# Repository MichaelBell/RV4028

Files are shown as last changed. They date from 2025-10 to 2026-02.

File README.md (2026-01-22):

# RV4028 - A hackable Risc-V computer

RV4028 is intended to be a modular Risc-V computer, similar to the excellent [RC2014 Z80](https://rc2014.co.uk/) homebrew computer.

The idea is to create a minimal Risc-V system that is easy to understand and extend.

The inspiration for this came from [@theJPster](https://github.com/thejpster)'s [post](https://bsky.app/profile/thejpster.org.uk/post/3m3ngtx5sfc2i).

All hardware and software are open source and permissively licensed.

## Architecture

The system bus has a 32-bit address and 16-bit data, which fits reasonably well with an RV32 system and readily available (P)SRAM chips, and runs at 3.3V.

Modules are attached by an 80-pin dual row header, similar to RC2014 modules but with 2 rows of pins instead of 1.  2mm pitch headers are used instead of 2.54mm, this makes boards slightly smaller (and cheaper), and also avoids the possibility of boards being plugged into RC2014 by mistake.

However, the pinout is chosen such that RC2014 modules might be compatible, if 3v3 capable components are used and a backplane with additional 2.54mm pitch sockets were created.  The pinout is also chosen such that modules not requiring access to the full bus can use just a single row.

Bus connector

## Software

The intention is to be able to run standard RV32I programs with a C SDK.  A Micropython port and Rust support are likely.

It is currently not a goal to support either real time operating systems (although this may be possible in future), or Linux (which would likely not be possible without moving to a larger FPGA).

# Initial modules

## CPU

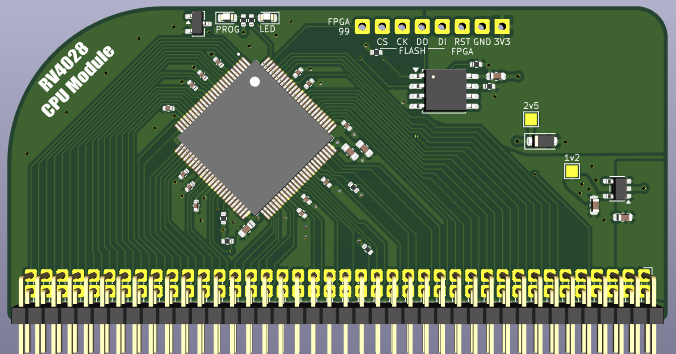
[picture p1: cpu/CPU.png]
CPU Module render


Keeping things minimal and simple, we use a Bruno Levy's [FemtoRV](https://github.com/BrunoLevy/learn-fpga/tree/master/FemtoRV) Quark (RV32I) core with some small modifications, and a wrapper to handle breaking each 32-bit data access into 16-bit accesses.  This is the most minimal Risc-V instruction set and can fit in a small FPGA, so we use an ICE40 [HX1K](https://www.latticesemi.com/ice40), which is available in a 100-pin QFP.

A small flash is required for the FPGA configuration, a header will be provided that will allow the FPGA to be held in reset and the flash programmed.  Although it is significantly larger than required, using a 1MB [W25Q80DV](https://www.lcsc.com/datasheet/C14086.pdf) seems cost effective. 

[Schematic](cpu/cpu.pdf)

## RAM

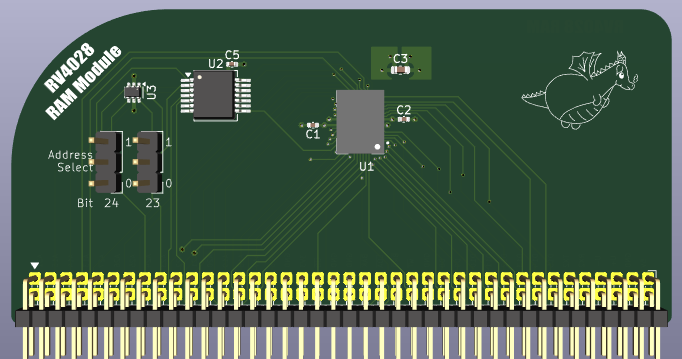
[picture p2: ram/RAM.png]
RAM Module render


The two candidates here are PSRAM, such as the [IS66WVE](https://www.lcsc.com/datasheet/C1350157.pdf), or SRAM such as the [CY7C1041G30](https://www.lcsc.com/datasheet/C2944680.pdf).

The PSRAM is larger but slower, and the larger capacities only seem available in BGA packages.  The linked SRAM is available in TSOP, which may allow for easier assembly.

The current RAM module uses the PSRAM.

[Schematic](ram/ram.pdf)

## ROM

Something like [SST39VF3202C](https://www.lcsc.com/datasheet/C637403.pdf) looks suitable, and available at the same access speed as the PSRAM (70ns).

ROM might not be required - we can embed a small amount of ROM (6kB) in the CPU gateware which could be enough for a simple SD card driver, allowing a program to be loaded from SD card to RAM without any ROM.

## IO

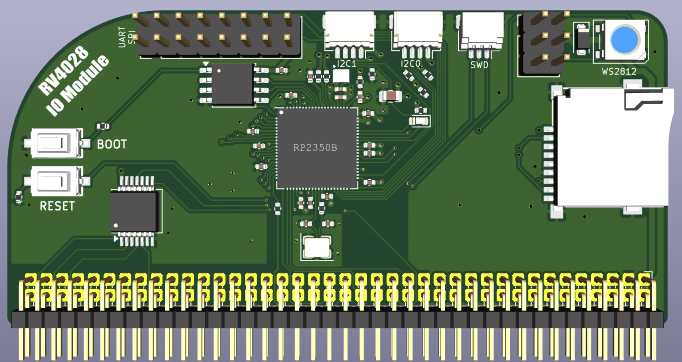
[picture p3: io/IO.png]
IO Module render


An [RP2350B](https://datasheets.raspberrypi.com/rp2350/rp2350-datasheet.pdf) is used for IO.  The board should include:
- Two UARTs
- Two I2C broken out to Qw/ST compatible ports
- A micro SD card socket
- An SPI with a couple of chip selects (this should be made easy to connect to the CPU for updating the gateware)
- Some GPIO

8 bits of address should easily be sufficient, and 8 bits of data should also be fine, which allows this to be single row.

I'm tempted to put USB on a couple of the spare backplane pins, so a single USB connection can power the system and be used to communicate with/program the RP2350.

If we also wired clock and reset from the RP2350 then it could provide a clock, meaning a separate clock module would not be required.

[Schematic](io/io.pdf) | [More details](io/README.md)

## Clock

As above, a clock module likely won't be required, but it is a nice educational addition, and would allow the machine to be used without the RP2350 based IO module.

A 14.7456MHz crystal would seem appropriate - double the clock rate of the RC2014.  Assuming IS66WVE PSRAM is used, the maximum reliable clock rate of the system should be around 17-18MHz (TBC).

An [SN74LVC1GX04](https://www.lcsc.com/datasheet/C2653063.pdf) could be used to drive the crystal.

## Backplane

USB-C socket, with data wired to spare pins for RP2350 on IO board.

AP2112K for 3.3V supply.  3v3 enable is delayed by a few milliseconds to help with power sequencing on the CPU board (the core power to the FPGA should be applied before IO voltage).

Decoupling caps, LED, reset button.  Use surface mount headers for the 2x40 pin connectors, allows all the signals to run above a nice unbroken ground plane, rather than having loads of through holes breaking up the ground planes.

# Bus timing

Addresses are always 16-bit aligned and a byte mask is used for single byte stores.

All writes complete in a two cycles.  Reads normally complete in two cycles, but wait may be asserted to extend the read cycle.

MREQ is intended to be wired to the (P)SRAM CE, so must be pulsed regularly even if reads are continuous in order to avoid exceeding max CE assertion time on PSRAM.  This is acheived by pulsing it high in the first half clock of each read cycle.  MREQ remains low at the start of a write cycle in order to support a faster clock speed when used with a IS66WVE.

IORQ is not required as the address space is sufficiently large.  It is simply set to ~A31.

LO_ADDR indicates if the address is in the bottom 16MB of the address space, to reduce the amount of address checking logic required on low addressed modules.

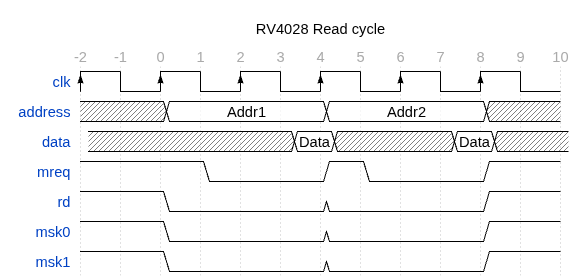
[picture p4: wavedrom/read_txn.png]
Read timing diagram


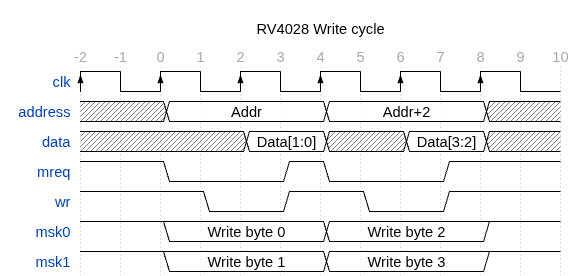
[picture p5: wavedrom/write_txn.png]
Write timing diagram


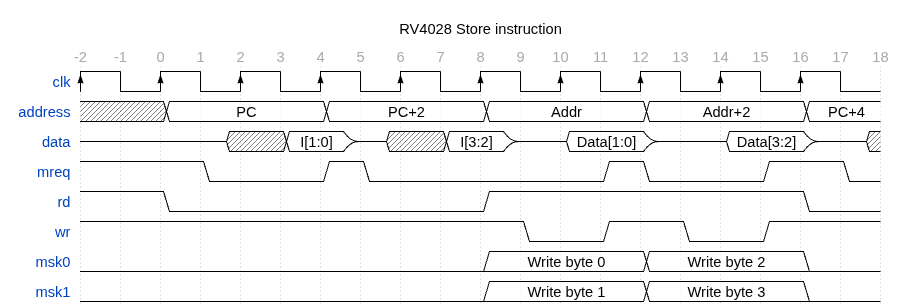
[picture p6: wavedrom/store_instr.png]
Full store instruction


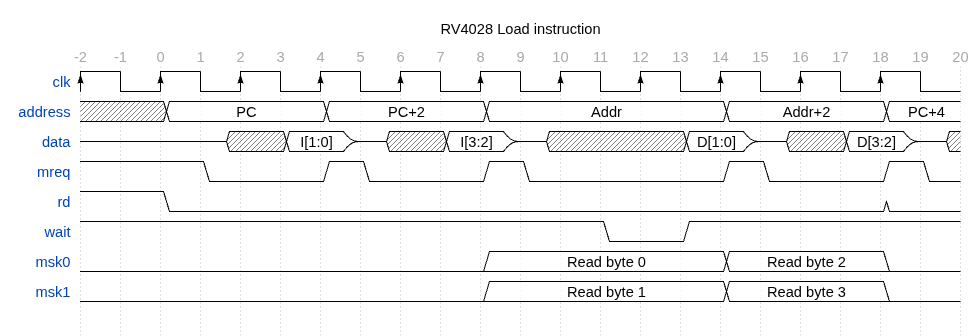
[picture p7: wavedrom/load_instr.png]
Full load instruction


## Expected RAM implementation

RAM access is controlled by CE, OE, WE and byte selects.

* Address high bits are compared for the chip, CE is never asserted if the address doesn't match
* CE is MREQ
* WE is WR
* OE is RD
* Byte selects are MSK.

Writes are latched by deasserting WE and CE.  So a full store instruction that read the instruction and wrote data back to the same RAM chip would look like:

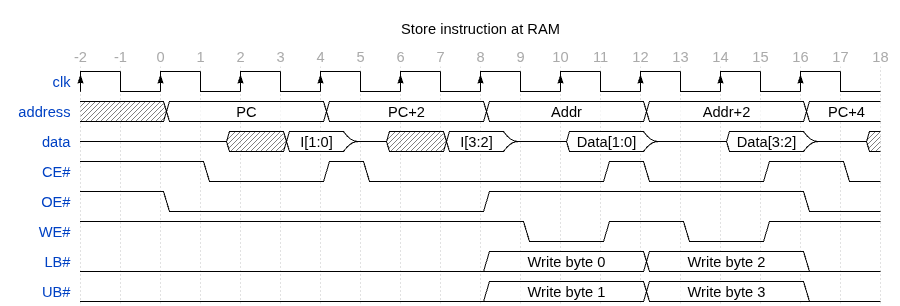
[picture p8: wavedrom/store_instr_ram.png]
Full store instruction to RAM


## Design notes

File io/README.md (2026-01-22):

# RP2350 IO module for RV4028

## Features

Basic idea is to expose the RP2350's hardware blocks as memory mapped peripherals.

Peripherals:
- 2 UARTs (one to backplane, one on headers)
- 2 I2C (QwST connectors)
- 1 SPI with 3 or 4 chip selects (can be used for programming the FPGA)
- SD card
- Maybe a WS2812 interface (exposing 5V power)
- Further pins as general purpose IO.  Maybe could expose a PIO block?

Clock and reset are connected, and can optionally be driven, depending on the loaded firmware.

WAIT and INT should be connected.

Other wiring:
- USB to the USB pins on the backplane
- SWD to a header

## Interface

Byte at a time data - this is very suitable for UART, I2C, SPI.

Address - A1-A7 connected, plus ~A31 and A30-A28 ORed together, with the module selected when the result is low.  The modules canonical address space is therefore even addresses within 0x8FFF_FF00 - 0x8FFF_FFFF.  Accessing it at other addresses should be avoided to prevent conflicting responses from different modules (maybe we put some protection in the gateware to prevent access to invalid addresses?)

IOSEL = ~A31 OR A30 OR A29 OR A28, RDREQ = REQ OR RD and WR are needed in addition to the 7 low address pins and 8 data pins.

## Implementation

PIO programs are used to detect read and write accesses.

### Write

Watches for WR going low and then checks IOSEL, if it is high the transaction is not for this module.

If low, the address and data pins are DMA'd from the PIO into a ring buffer and an IRQ asserted to wake a CPU task to read the ring buffer.

The CPU reads while the ring buffer is not empty, and forwards the data to the peripheral based on the memory map.

PIO waits for WR to go high.

### Read

Watches for RDREQ going low and then checks IOSEL, if it is high the transaction is not for this module.

If low, the address is DMA'd to the trigger read address of a waiting DMA channel.  This reads from a table of source addresses into the read trigger address of a second waiting DMA channel, which will DMA one byte from (normally) a peripheral address to the PIO, which will set the data pins.  When RDREQ goes high the data are set back to inputs and the PIO resets.

Latency from RDREQ going low to data being presented should be around 10-15 cycles:
- Wait (2 cycles input latency)
- Jmp
- In pins (auto push)
- DMA trigger
- DMA read from lookup table
- DMA write and trigger
- DMA read from peripheral
- Out pins (auto pull)

This has a little less than 1.5 cycles to complete if WAIT isn't asserted, so is rather tight but should work if the RP2350 clock is > 12x faster than the RV4028 clock.  Could do with prototyping to check the cycle count is acheivable.

### Pin mapping

0-1 UART0 to header
2-3 Ground, so they will read as zero
4-10 A1-A7
11-18 D0-D7
19 CLK
20 RESET
21 INT
22 WAIT
23 IOSEL
24 WR
25 RD
26-27 UART1 to backplane
28-31 SPI1
32-33 I2C0
34-39 SD card (SPI0)
40-41 Additional SPI chip selects
42-43 I2C1
44 WS2812b LED data
45 LED
46-47 GPIO

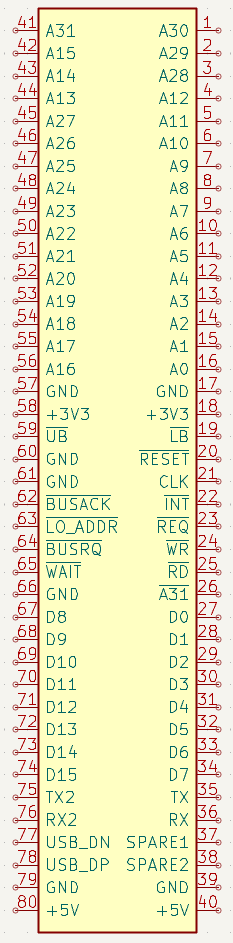
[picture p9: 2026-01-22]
BusConn.png

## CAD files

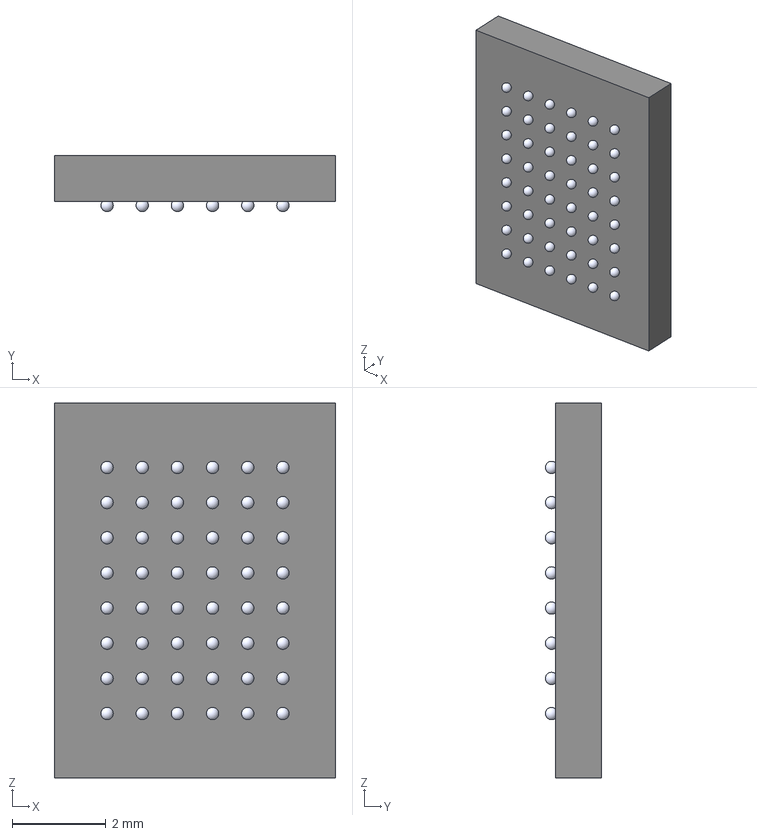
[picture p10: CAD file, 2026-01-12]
kicad/IS66WVE4M16EBLL-70BLI/IS66WVE4M16EBLL-70BLI.step
6.00 x 1.20 x 8.00 mm
Body_Solid1
Body002_Solid1
BALL_0001
BALL_0002
BALL_0003
BALL_0004
BALL_0005
BALL_0006
BALL_0007
BALL_0008
BALL_0009
BALL_0010
BALL_0011
BALL_0012
BALL_0013
BALL_0014
BALL_0015
BALL_0016
BALL_0017
BALL_0018
BALL_0019
BALL_0020
BALL_0021
BALL_0022
BALL_0023
BALL_0024
BALL_0025
BALL_0026
BALL_0027
BALL_0028
BALL_0029
BALL_0030
BALL_0031
BALL_0032
BALL_0033
BALL_0034
BALL_0035
BALL_0036
BALL_0037
BALL_0038
BALL_0039
BALL_0040
BALL_0041
BALL_0042
BALL_0043
BALL_0044
BALL_0045
BALL_0046
BALL_0047
BALL_0048

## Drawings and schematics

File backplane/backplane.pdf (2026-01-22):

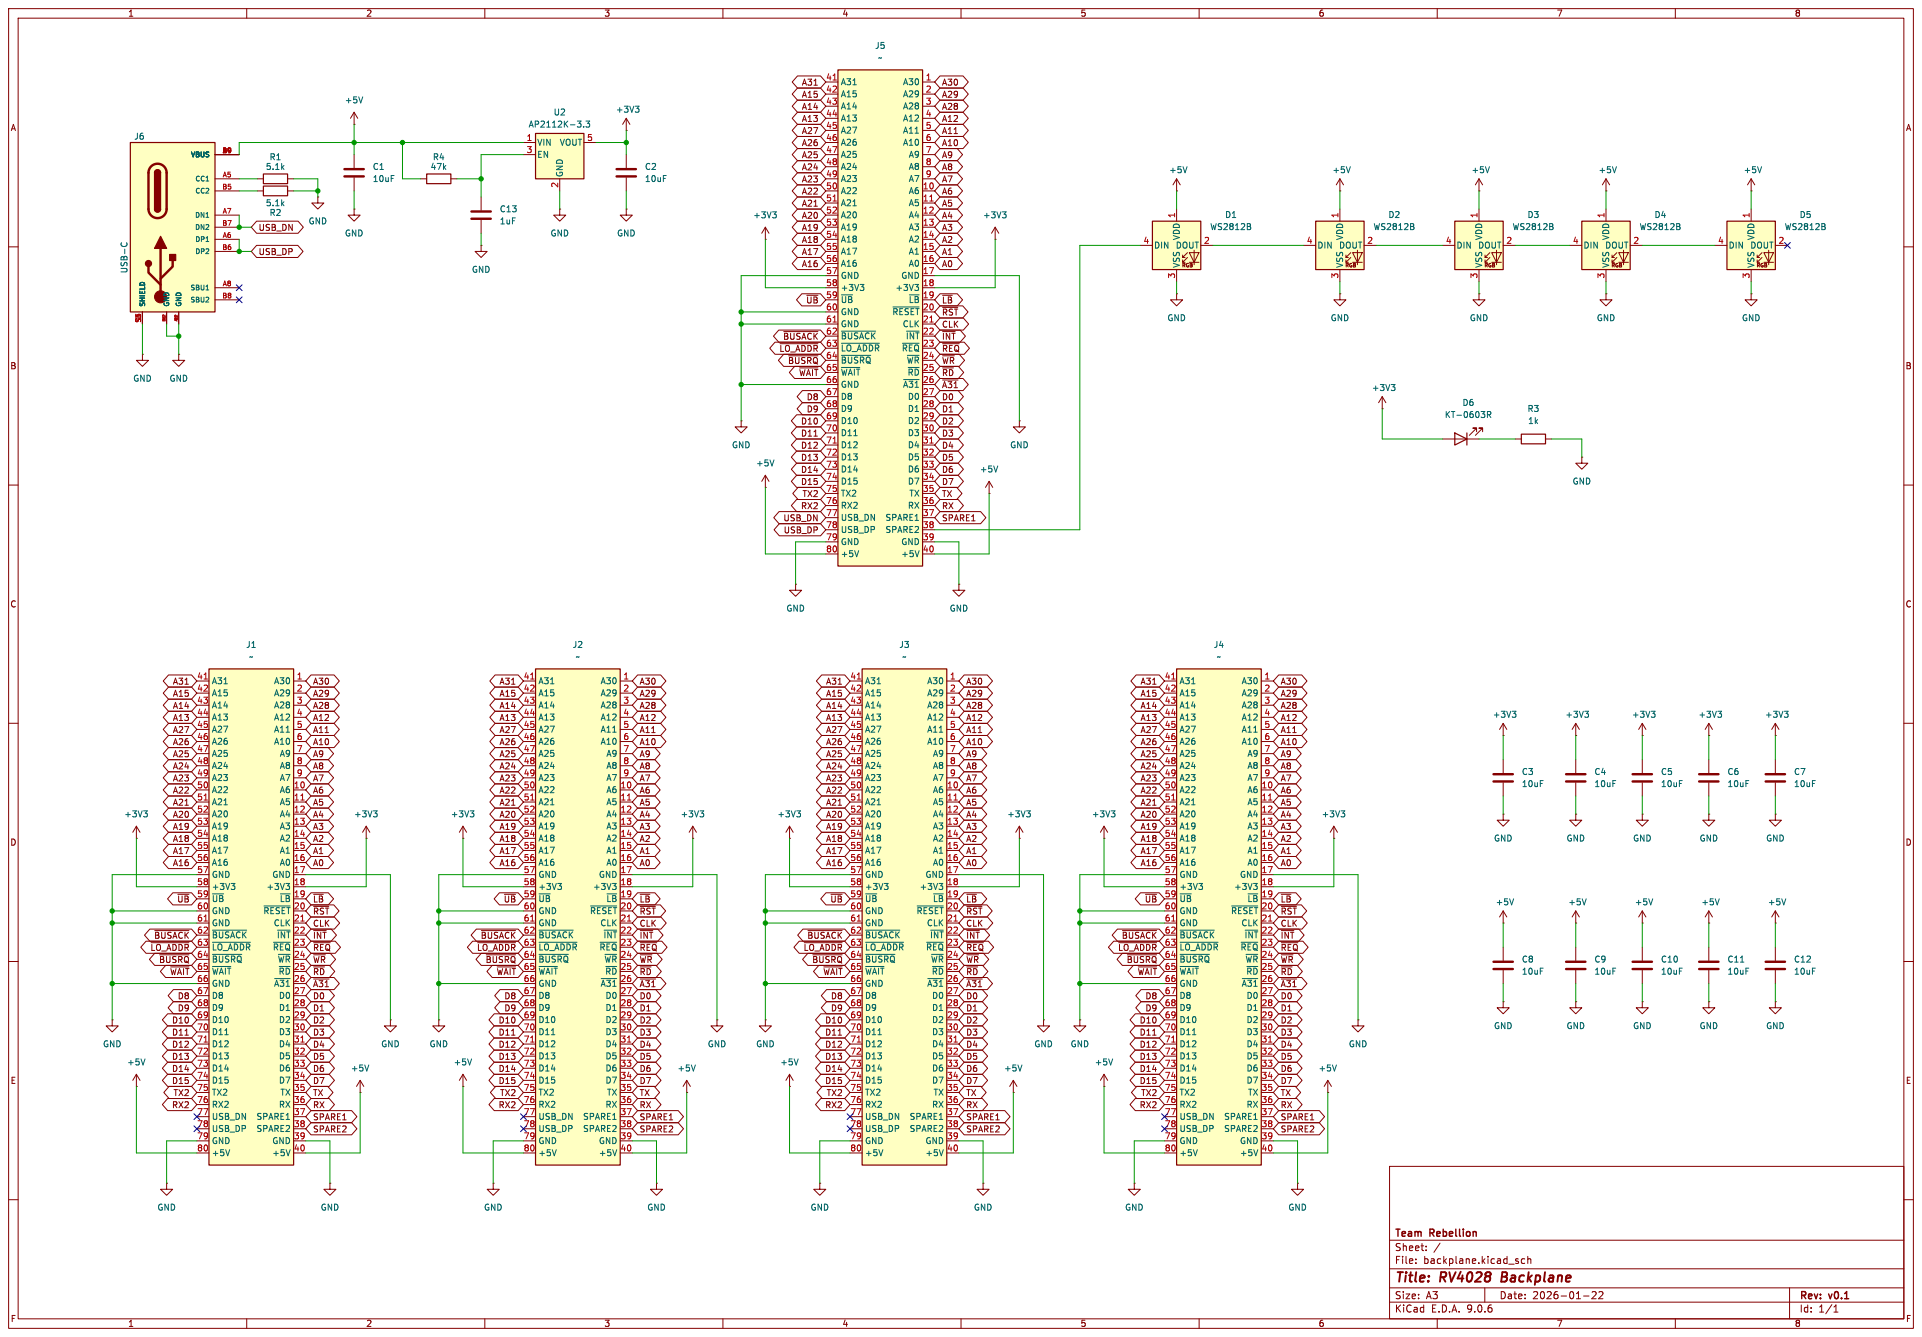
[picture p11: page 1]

1S34 CC1 A5 CC2 B5 DN1 A7 DN2 B7 DP1 A6 DP2 B6 SBU1 A8 SBU2 B8 SHIELD S1 GND A1 B12 GND A12 B1 VBUS B49A J6 USB-C

A30 1 A29 2 A28 3 A12 4 A11 5 A10 6 A9 7 A8 8 A7 9 A6 10 A5 11 A4 12 A3 13 A2 14 A1 15 A0 16 GND 17 +3V3 18 ~{LB}19 ~{RESET} 20 CLK 21 ~{INT} 22 ~{REQ} 23 ~{WR} 24 ~{RD} 25 ~{A31}26 D0 27 D1 28 D2 29 D3 30 D4 31 D5 32 D6 33 D7 34 TX 35 RX 36 SPARE1 37 SPARE2 38 GND 39 +5V 40 ~{BUSACK} 62

USB_DP

A31 41 A15 42 A14 43 A13 44 A27 45 A26 46 A25 47 A24 48 A23 49 A22 50 A21 51 A20 52 A19 53 A18 54 A17 55 A16 56 GND 57 +3V3 58 ~{UB} 59 GND 60 GND 61 ~{LO_ADDR} 63 ~{BUSRQ} 64 ~{WAIT} 65 GND 66 D8 67 D9 68 D10 69 D11 70 D12 71 D13 72 D14 73 D15 74 TX2 75 RX2 76 USB_DN 77 USB_DP 78 GND 79 +5V 80

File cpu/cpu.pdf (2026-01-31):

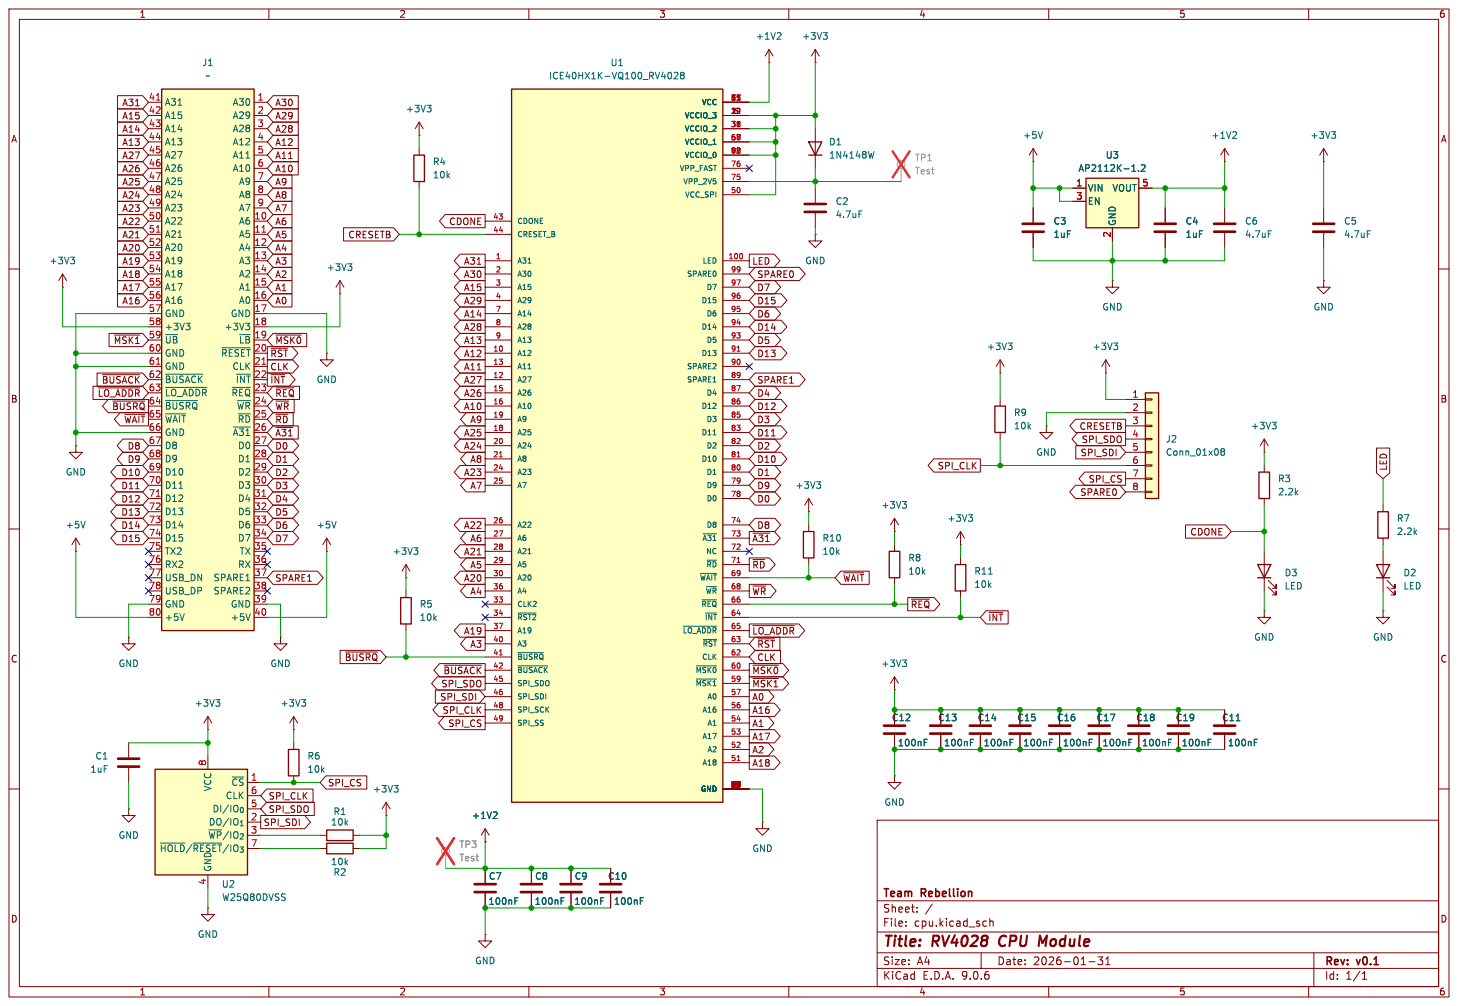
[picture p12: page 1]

~{CS}1 CLK 6 DI/IO_{0}5 DO/IO_{1}2 ~{WP}/IO_{2} 3 ~{HOLD}/~{RESET}/IO_{3} 7 VCC

Id: 1/1 Title: RV4028 CPU Module

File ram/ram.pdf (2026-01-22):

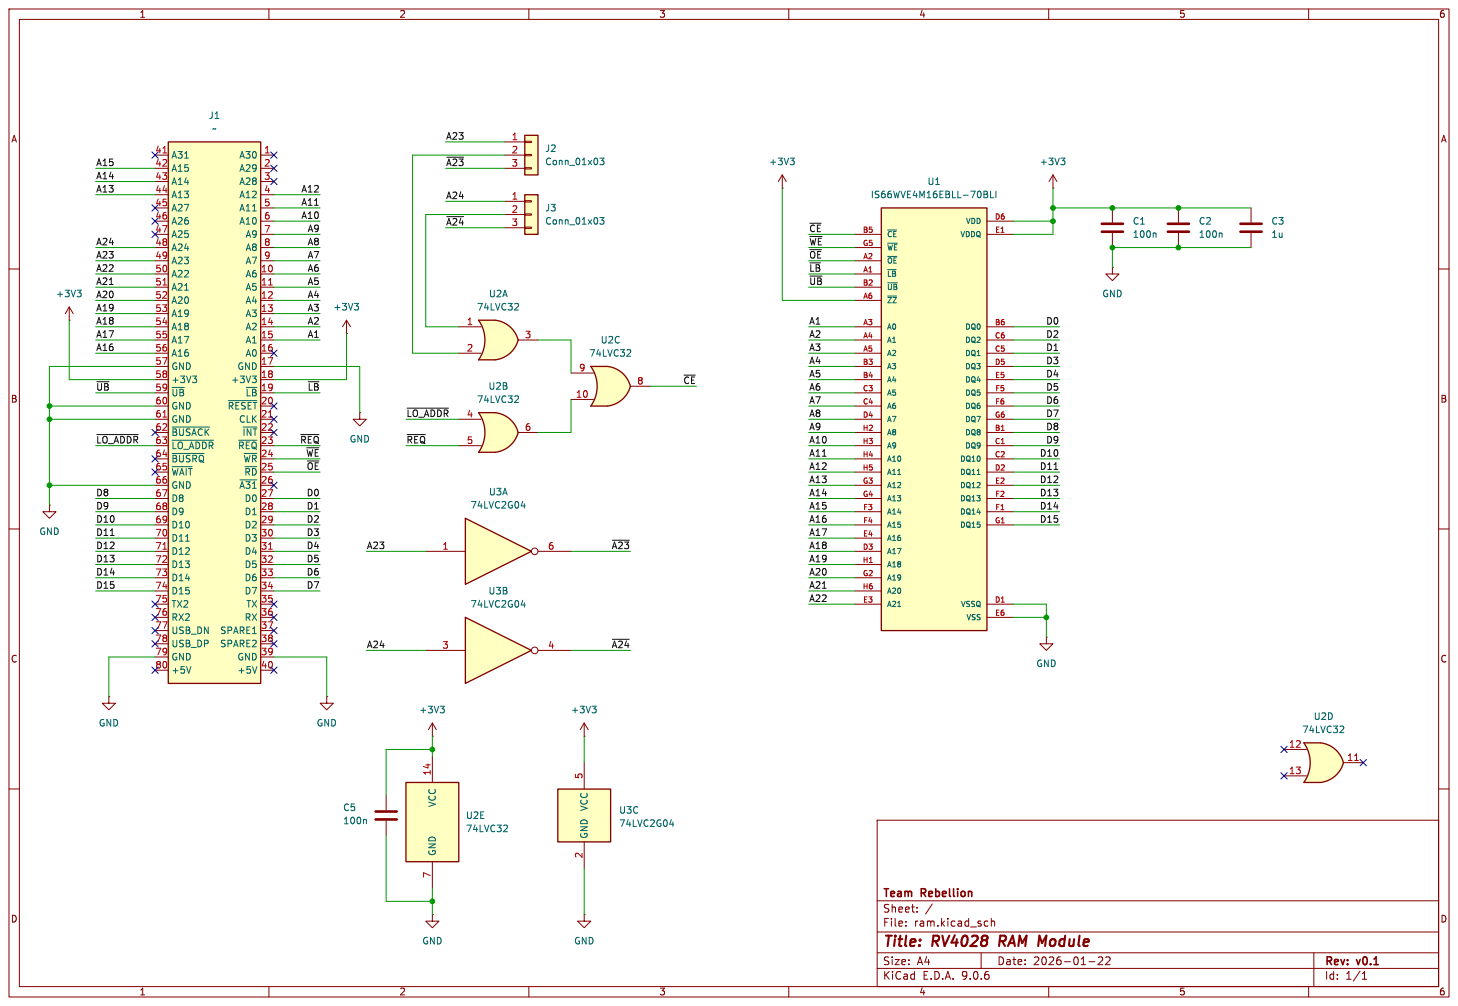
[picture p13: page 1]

Id: 1/1 Title: RV4028 RAM Module

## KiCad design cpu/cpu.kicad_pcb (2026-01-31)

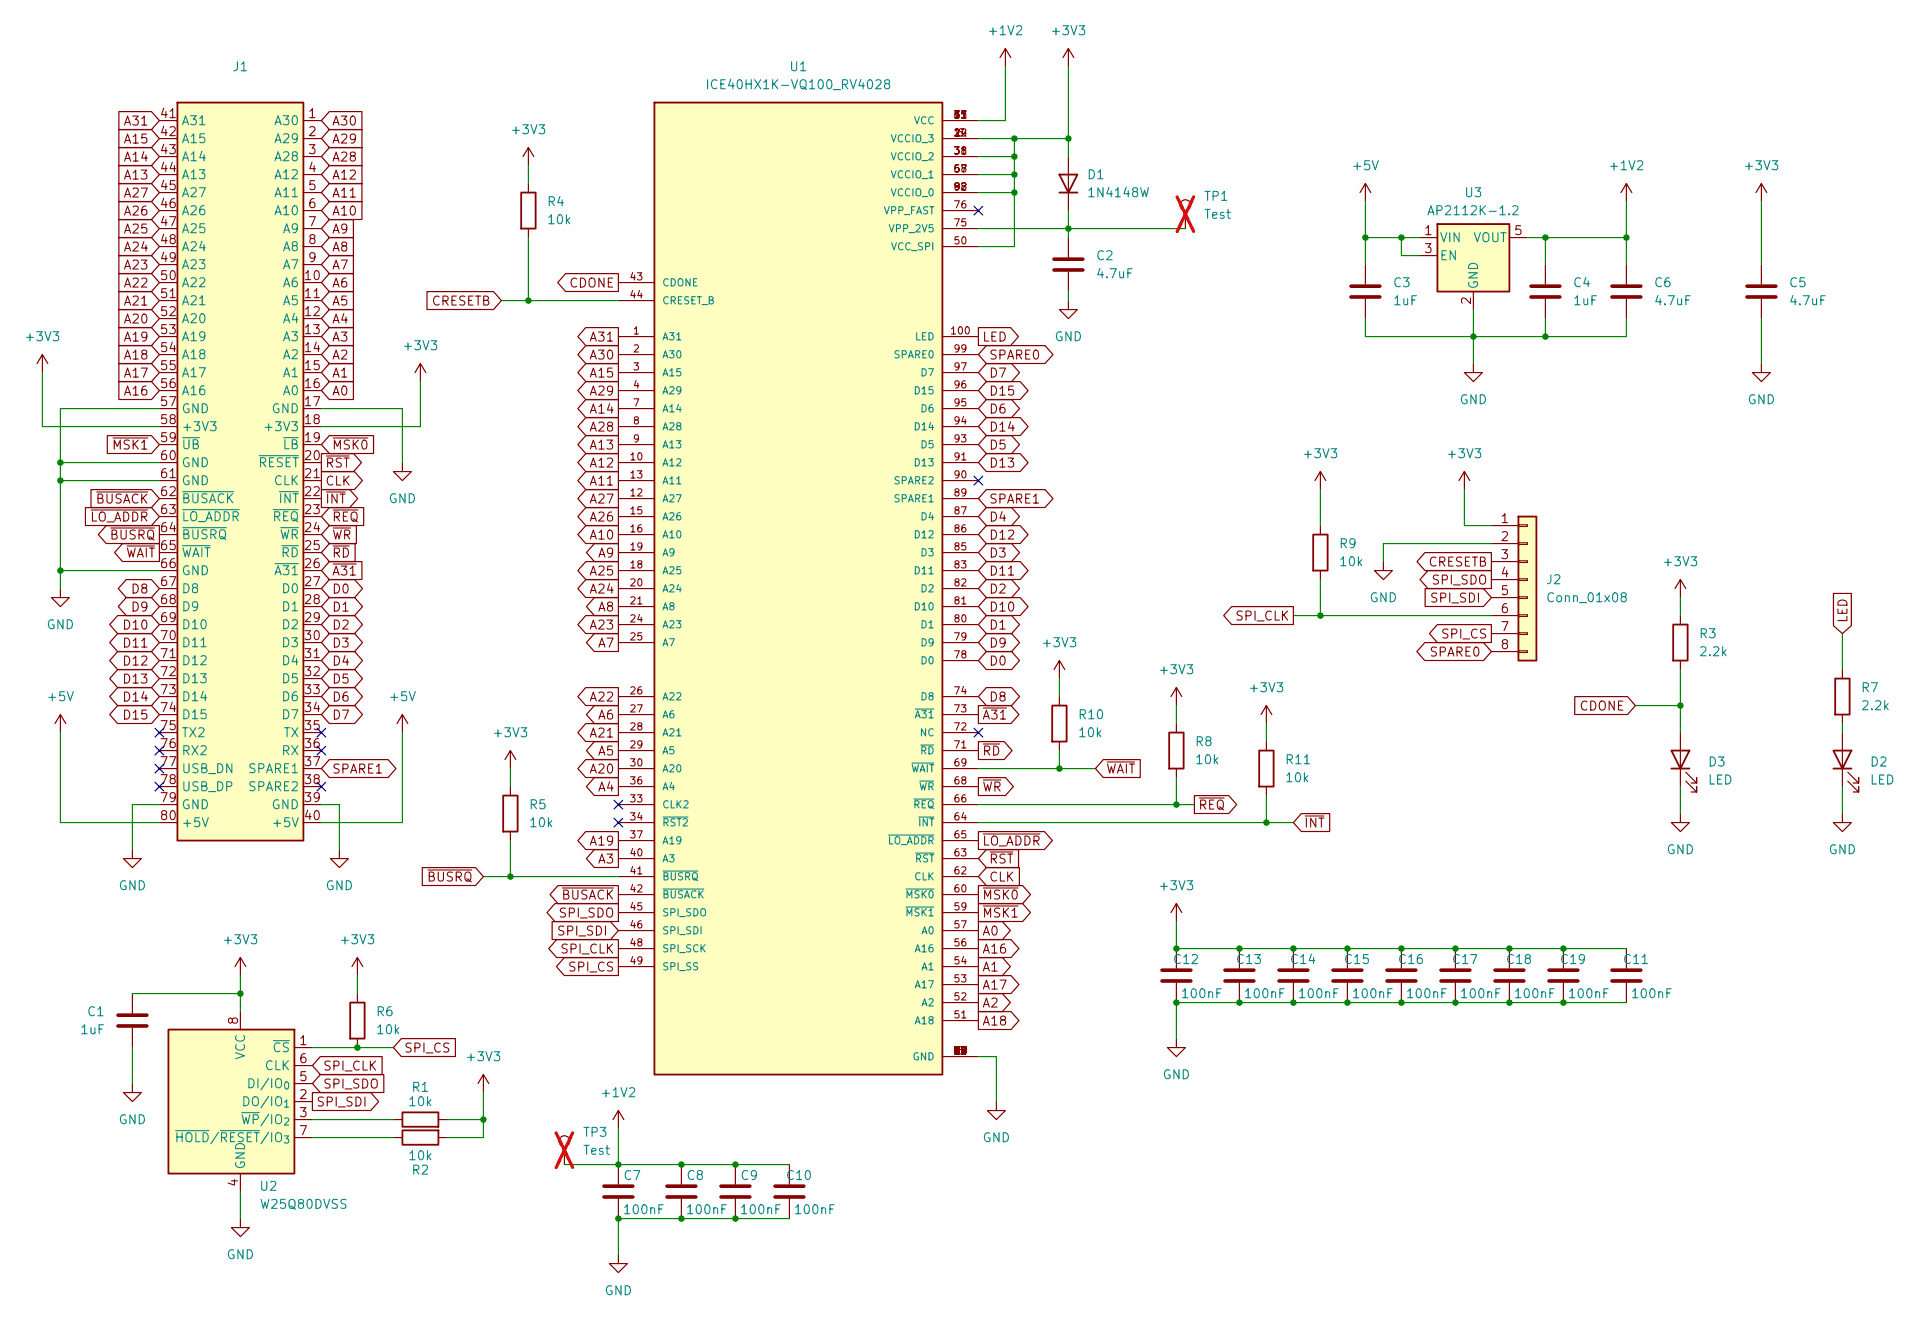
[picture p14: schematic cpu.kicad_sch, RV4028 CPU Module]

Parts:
C1, C3, C4: 1uF; C_0603_1608Metric; JLC C15849
C2, C5, C6: 4.7uF; C_0603_1608Metric; JLC C19666
C7, C8, C9, C10, C11, C12, C13, C14, C15, C16, C17, C18, C19: 100nF; C_0402_1005Metric; JLC C1525
D1: 1N4148W; D_SOD-123F; JLC C81598
D2: LED; LED_0603_1608Metric; JLC C2286
D3: LED; LED_0603_1608Metric; JLC C2290
J1: Module_2mm; JLC C3407
J2: Conn_01x08; PinHeader_1x08_P2.54mm_Vertical; JLC C5383116
R1, R2, R4, R5, R6, R8, R9, R10, R11: 10k; R_0402_1005Metric; JLC C25744
R3, R7: 2.2k; R_0402_1005Metric; JLC C25879
TP1, TP3: Test; TestPoint_Pad_1.5x1.5mm; not fitted
U1: ICE40HX1K-VQ100_RV4028; QFP50P1600X1600X120-100N; PARTREV 3.4; JLC C1519043
U2: W25Q80DVSS; SOIC-8_5.3x5.3mm_P1.27mm; JLC C14086
U3: AP2112K-1.2; SOT-23-5; JLC C460310

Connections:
+1V2: C4.1, C6.1, C7.2, C8.2, C9.2, C10.2, TP3.1, U1.11 (VCC), U1.35 (VCC), U1.61 (VCC), U1.77 (VCC), U3.5 (VOUT)
+3V3: C1.2, C5.1, C11.2, C12.2, C13.2, C14.2, C15.2, C16.2, C17.2, C18.2, C19.2, D1.2 (A), J1.18 (+3V3), J1.58 (+3V3), J2.1, R1.2, R2.2, R3.1, R4.1, R5.1, R6.1, R8.1, R9.1, R10.1, R11.1, U1.6 (VCCIO_3), U1.14 (VCCIO_3), U1.22 (VCCIO_3), U1.31 (VCCIO_2), U1.38 (VCCIO_2), U1.50 (VCC_SPI), U1.58 (VCCIO_1), U1.67 (VCCIO_1), U1.88 (VCCIO_0), U1.92 (VCCIO_0), U2.8 (VCC)
+5V: C3.1, J1.40 (+5V), J1.80 (+5V), U3.1 (VIN), U3.3 (EN)
A0: J1.16 (A0), U1.57 (A0)
A1: J1.15 (A1), U1.54 (A1)
A2: J1.14 (A2), U1.52 (A2)
A3: J1.13 (A3), U1.40 (A3)
A4: J1.12 (A4), U1.36 (A4)
A5: J1.11 (A5), U1.29 (A5)
A6: J1.10 (A6), U1.27 (A6)
A7: J1.9 (A7), U1.25 (A7)
A8: J1.8 (A8), U1.21 (A8)
A9: J1.7 (A9), U1.19 (A9)
A10: J1.6 (A10), U1.16 (A10)
A11: J1.5 (A11), U1.13 (A11)
A12: J1.4 (A12), U1.10 (A12)
A13: J1.44 (A13), U1.9 (A13)
A14: J1.43 (A14), U1.7 (A14)
A15: J1.42 (A15), U1.3 (A15)
A16: J1.56 (A16), U1.56 (A16)
A17: J1.55 (A17), U1.53 (A17)
A18: J1.54 (A18), U1.51 (A18)
A19: J1.53 (A19), U1.37 (A19)
A20: J1.52 (A20), U1.30 (A20)
A21: J1.51 (A21), U1.28 (A21)
A22: J1.50 (A22), U1.26 (A22)
A23: J1.49 (A23), U1.24 (A23)
A24: J1.48 (A24), U1.20 (A24)
A25: J1.47 (A25), U1.18 (A25)
A26: J1.46 (A26), U1.15 (A26)
A27: J1.45 (A27), U1.12 (A27)
A28: J1.3 (A28), U1.8 (A28)
A29: J1.2 (A29), U1.4 (A29)
A30: J1.1 (A30), U1.2 (A30)
A31: J1.41 (A31), U1.1 (A31)
CDONE: D3.2 (A), R3.2, U1.43 (CDONE)
CLK: J1.21 (CLK), U1.62 (CLK)
CRESETB: J2.3, R4.2, U1.44 (CRESET_B)
D0: J1.27 (D0), U1.78 (D0)
D1: J1.28 (D1), U1.80 (D1)
D2: J1.29 (D2), U1.82 (D2)
D3: J1.30 (D3), U1.85 (D3)
D4: J1.31 (D4), U1.87 (D4)
D5: J1.32 (D5), U1.93 (D5)
D6: J1.33 (D6), U1.95 (D6)
D7: J1.34 (D7), U1.97 (D7)
D8: J1.67 (D8), U1.74 (D8)
D9: J1.68 (D9), U1.79 (D9)
D10: J1.69 (D10), U1.81 (D10)
D11: J1.70 (D11), U1.83 (D11)
D12: J1.71 (D12), U1.86 (D12)
D13: J1.72 (D13), U1.91 (D13)
D14: J1.73 (D14), U1.94 (D14)
D15: J1.74 (D15), U1.96 (D15)
GND: C1.1, C2.2, C3.2, C4.2, C5.2, C6.2, C7.1, C8.1, C9.1, C10.1, C11.1, C12.1, C13.1, C14.1, C15.1, C16.1, C17.1, C18.1, C19.1, D2.1 (K), D3.1 (K), J1.17 (GND), J1.39 (GND), J1.57 (GND), J1.60 (GND), J1.61 (GND), J1.66 (GND), J1.79 (GND), J2.2, U1.5 (GND), U1.17 (GND), U1.23 (GND), U1.32 (GND), U1.39 (GND), U1.47 (GND), U1.55 (GND), U1.70 (GND), U1.84 (GND), U1.98 (GND), U2.4 (GND), U3.2 (GND)
LED: R7.1, U1.100 (LED)
unnamed: C2.1, D1.1 (K), TP1.1, U1.75 (VPP_2V5)
unnamed: D2.2 (A), R7.2
unnamed: R2.1, U2.7 (~HOLD/~RESET/IO_{3})
unnamed: R1.1, U2.3 (~WP/IO_{2})
SPARE0: J2.8, U1.99 (SPARE0)
SPARE1: J1.37 (SPARE1), U1.89 (SPARE1)
SPI_CLK: J2.6, R9.2, U1.48 (SPI_SCK), U2.6 (CLK)
SPI_CS: J2.7, R6.2, U1.49 (SPI_SS), U2.1 (~CS)
SPI_SDI: J2.5, U1.46 (SPI_SDI), U2.2 (DO/IO_{1})
SPI_SDO: J2.4, U1.45 (SPI_SDO), U2.5 (DI/IO_{0})
~A31: J1.26 (~A31), U1.73 (~A31)
~BUSACK: J1.62 (~BUSACK), U1.42 (~BUSACK)
~BUSRQ: J1.64 (~BUSRQ), R5.2, U1.41 (~BUSRQ)
~INT: J1.22 (~INT), R11.2, U1.64 (~INT)
~LO_ADDR: J1.63 (~LO_ADDR), U1.65 (~LO_ADDR)
~MSK0: J1.19 (~LB), U1.60 (~MSK0)
~MSK1: J1.59 (~UB), U1.59 (~MSK1)
~RD: J1.25 (~RD), U1.71 (~RD)
~REQ: J1.23 (~REQ), R8.2, U1.66 (~REQ)
~RST: J1.20 (~RESET), U1.63 (~RST)
~WAIT: J1.65 (~WAIT), R10.2, U1.69 (~WAIT)
~WR: J1.24 (~WR), U1.68 (~WR)

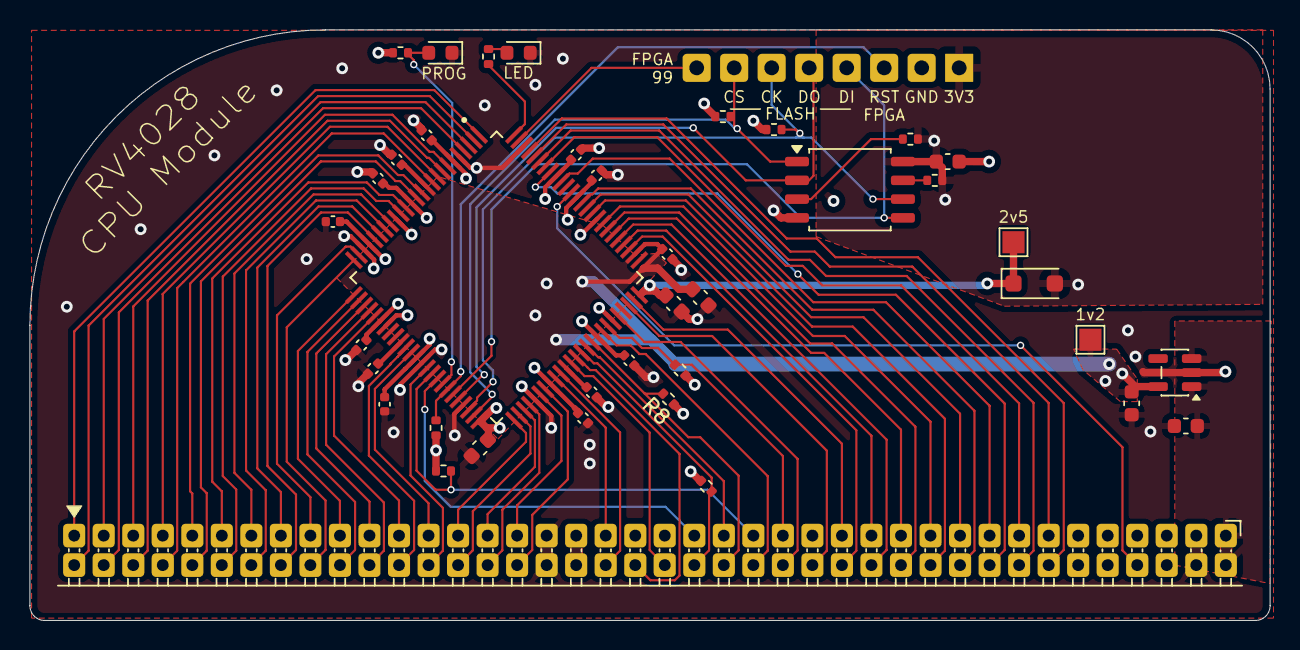
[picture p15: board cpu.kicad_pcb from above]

Board: 4 copper layers, 84.0 x 40.0 mm, 40 parts (0 on the bottom side), 78 nets.

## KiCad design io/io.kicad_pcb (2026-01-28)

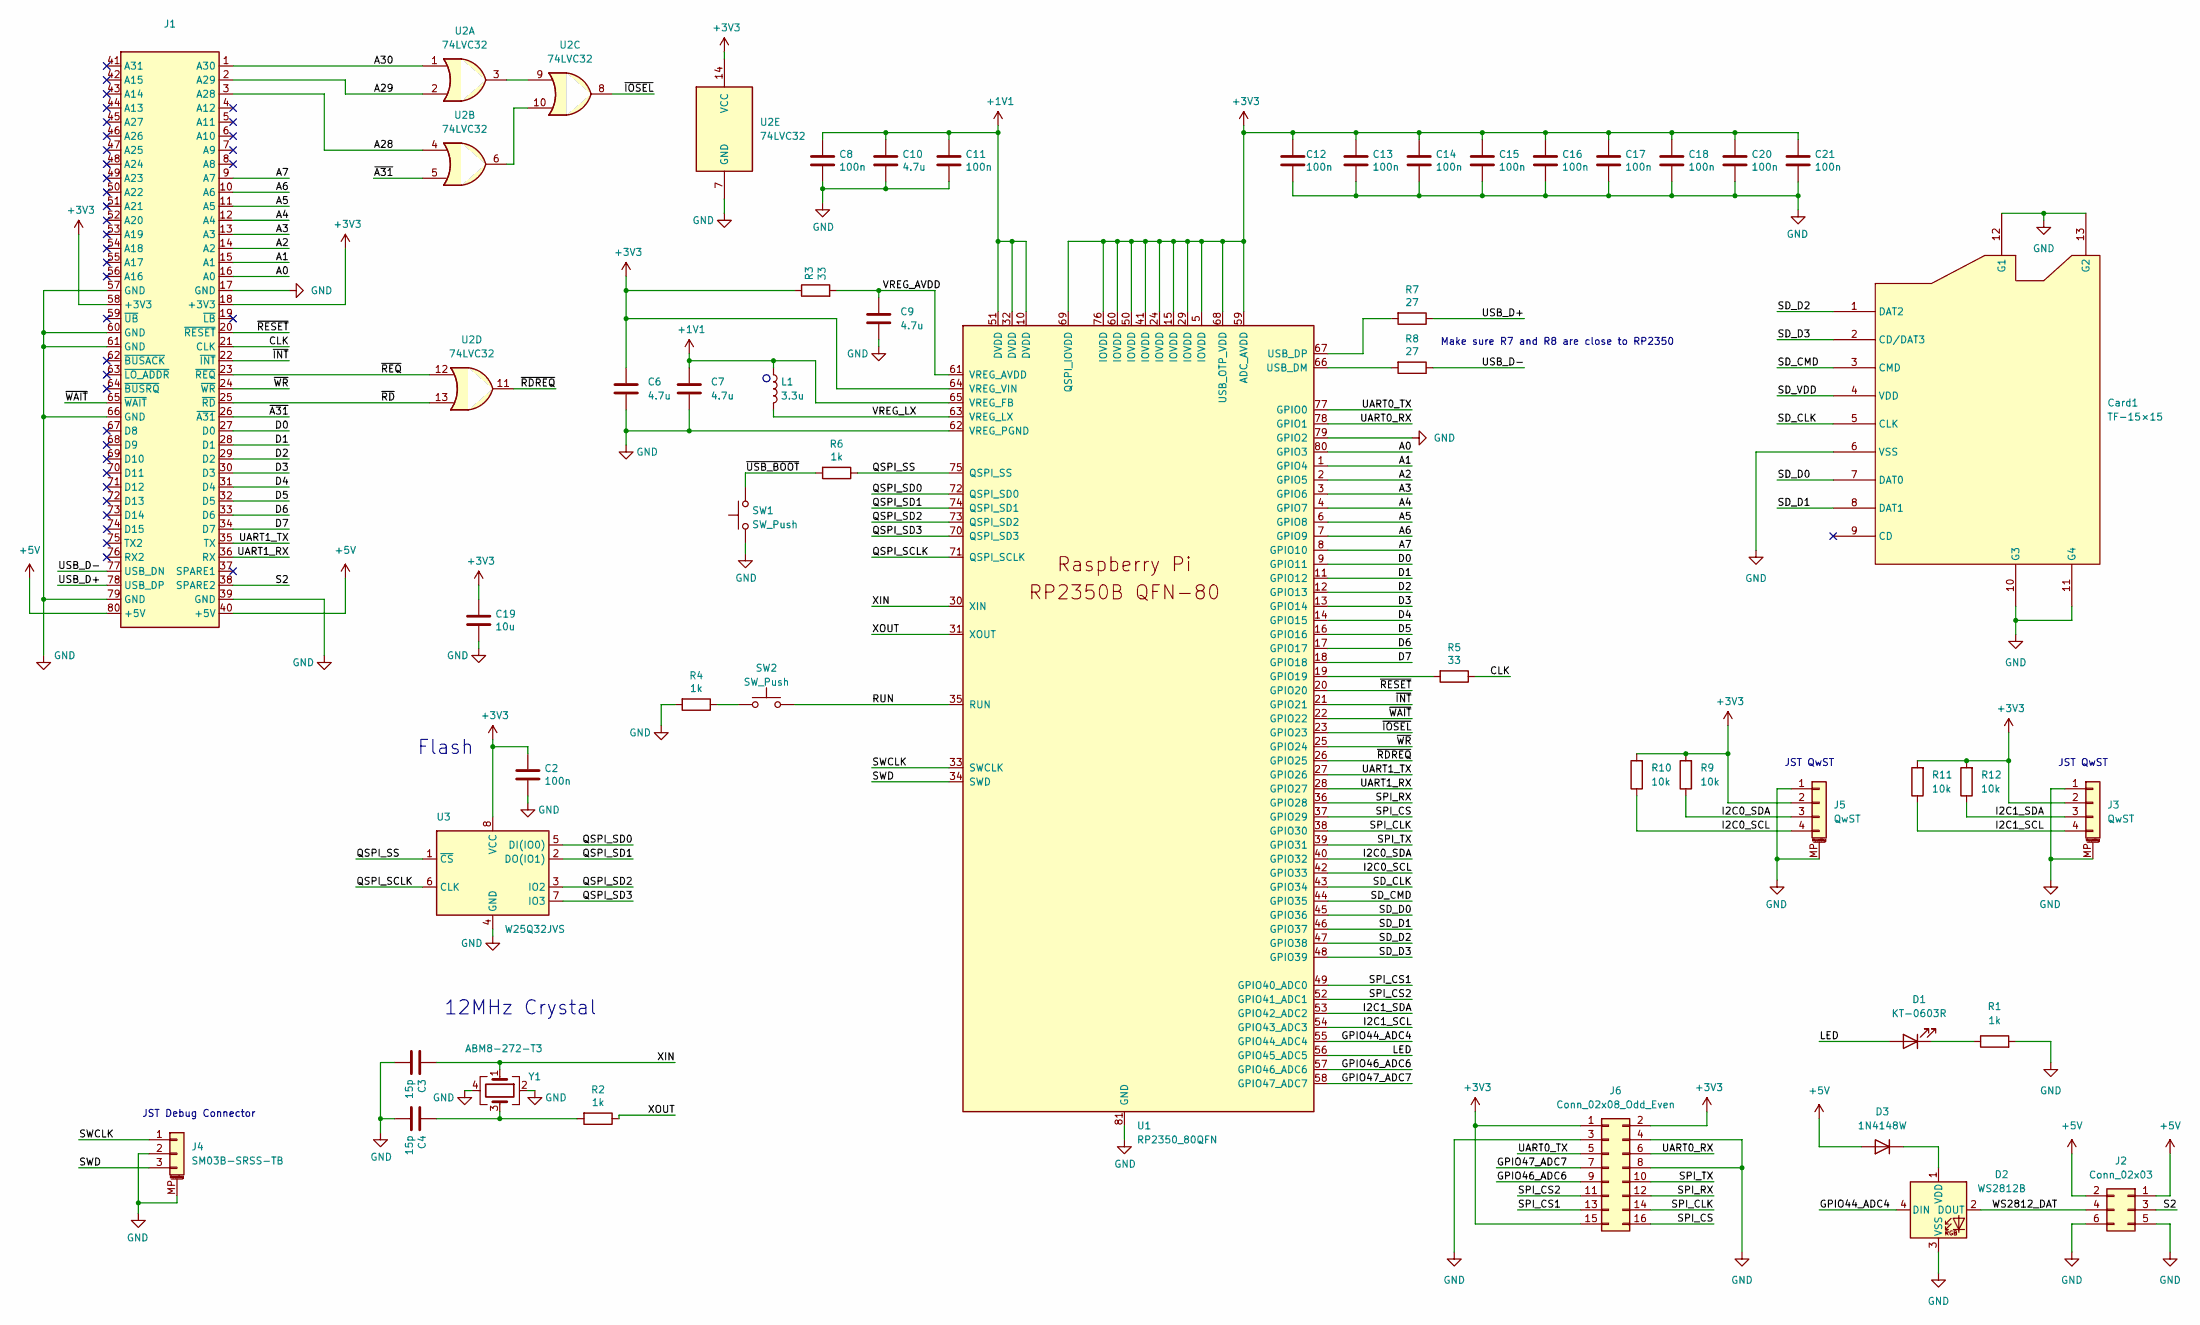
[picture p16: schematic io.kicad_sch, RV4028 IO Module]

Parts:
C2, C8, C11, C12, C13, C14, C15, C16, C17, C18, C20, C21: 100n; C_0402_1005Metric
C3, C4: 15p; C_0402_1005Metric
C6, C7: 4.7u; C_0402_1005Metric_small_pads
C9, C10: 4.7u; C_0402_1005Metric
C19: 10u; C_0805_2012Metric
Card1: TF-15×15; TF-SMD_TF-15-15; LCSC Part C111196
D1: KT-0603R; LED_0603_1608Metric; JLC C2286
D2: WS2812B; LED_WS2812B_PLCC4_5.0x5.0mm_P3.2mm; JLC C42417498
D3: 1N4148W; D_SOD-123F; JLC C81598
J1: Module_2mm; JLC C3407
J2: Conn_02x03; PinHeader_2x03_P2.54mm_Vertical; JLC C5383104
J3, J5: QwST; JST_SH_SM04B-SRSS-TB_1x04-1MP_P1.00mm_Horizontal; JLC C160404
J4: SM03B-SRSS-TB; JST_SH_SM03B-SRSS-TB_1x03-1MP_P1.00mm_Horizontal; JLC C160403
J6: Conn_02x08_Odd_Even; PinHeader_2x08_P2.54mm_Vertical; JLC C5383108
L1: 3.3u; L_pol_2016; JLC C42411119
R1, R2, R4, R6: 1k; R_0402_1005Metric
R3, R5: 33; R_0402_1005Metric
R7, R8: 27; R_0402_1005Metric
R9, R10, R11, R12: 10k; R_0402_1005Metric
SW1, SW2: SW_Push; SW-SMD_HX-TS-1101-C-W; JLC C36498960
U1: RP2350_80QFN; RP2350-QFN-80-1EP_10x10_P0.4mm_EP3.4x3.4mm_ThermalVias; JLC C42415655
U2: 74LVC32; SSOP-14_5.3x6.2mm_P0.65mm; JLC C2867091
U3: W25Q32JVS; SOIC-8_5.3x5.3mm_P1.27mm; JLC C179173
Y1: ABM8-272-T3; Crystal_SMD_3225-4Pin_3.2x2.5mm; JLC C20625731

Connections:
+1V1: C7.1, C8.1, C10.1, C11.1, L1.1, U1.10 (DVDD), U1.32 (DVDD), U1.51 (DVDD), U1.65 (VREG_FB)
+3V3: C2.1, C6.1, C12.1, C13.1, C14.1, C15.1, C16.1, C17.1, C18.1, C19.1, C20.1, C21.1, J1.18 (+3V3), J1.58 (+3V3), J3.2, J5.2, J6.1, J6.2, J6.15, R3.1, R9.2, R10.2, R11.2, R12.2, U1.5 (IOVDD), U1.15 (IOVDD), U1.24 (IOVDD), U1.29 (IOVDD), U1.41 (IOVDD), U1.50 (IOVDD), U1.59 (ADC_AVDD), U1.60 (IOVDD), U1.64 (VREG_VIN), U1.68 (USB_OTP_VDD), U1.69 (QSPI_IOVDD), U1.76 (IOVDD), U2.14 (VCC), U3.8 (VCC)
+5V: D3.2 (A), J1.40 (+5V), J1.80 (+5V), J2.1, J2.2
/A0: J1.16 (A0), U1.80 (GPIO3)
/A1: J1.15 (A1), U1.1 (GPIO4)
/A2: J1.14 (A2), U1.2 (GPIO5)
/A3: J1.13 (A3), U1.3 (GPIO6)
/A4: J1.12 (A4), U1.4 (GPIO7)
/A5: J1.11 (A5), U1.6 (GPIO8)
/A6: J1.10 (A6), U1.7 (GPIO9)
/A7: J1.9 (A7), U1.8 (GPIO10)
/A28: J1.3 (A28), U2.4
/A29: J1.2 (A29), U2.2
/A30: J1.1 (A30), U2.1
/CLK: J1.21 (CLK), R5.1
/D0: J1.27 (D0), U1.9 (GPIO11)
/D1: J1.28 (D1), U1.11 (GPIO12)
/D2: J1.29 (D2), U1.12 (GPIO13)
/D3: J1.30 (D3), U1.13 (GPIO14)
/D4: J1.31 (D4), U1.14 (GPIO15)
/D5: J1.32 (D5), U1.16 (GPIO16)
/D6: J1.33 (D6), U1.17 (GPIO17)
/D7: J1.34 (D7), U1.18 (GPIO18)
/GPIO44_ADC4: D2.4 (DIN), U1.55 (GPIO44_ADC4)
/GPIO46_ADC6: J6.9, U1.57 (GPIO46_ADC6)
/GPIO47_ADC7: J6.7, U1.58 (GPIO47_ADC7)
/I2C0_SCL: J5.4, R10.1, U1.42 (GPIO33)
/I2C0_SDA: J5.3, R9.1, U1.40 (GPIO32)
/I2C1_SCL: J3.4, R11.1, U1.54 (GPIO43_ADC3)
/I2C1_SDA: J3.3, R12.1, U1.53 (GPIO42_ADC2)
/LED: D1.2 (A), U1.56 (GPIO45_ADC5)
/QSPI_SCLK: U1.71 (QSPI_SCLK), U3.6 (CLK)
/QSPI_SD0: U1.72 (QSPI_SD0), U3.5 (DI(IO0))
/QSPI_SD1: U1.74 (QSPI_SD1), U3.2 (DO(IO1))
/QSPI_SD2: U1.73 (QSPI_SD2), U3.3 (IO2)
/QSPI_SD3: U1.70 (QSPI_SD3), U3.7 (IO3)
/QSPI_SS: R6.1, U1.75 (QSPI_SS), U3.1 (~CS)
/RUN: SW2.2, U1.35 (RUN)
/S2: J1.38 (SPARE2), J2.3
/SD_CLK: Card1.5 (CLK), U1.43 (GPIO34)
/SD_CMD: Card1.3 (CMD), U1.44 (GPIO35)
/SD_D0: Card1.7 (DAT0), U1.45 (GPIO36)
/SD_D1: Card1.8 (DAT1), U1.46 (GPIO37)
/SD_D2: Card1.1 (DAT2), U1.47 (GPIO38)
/SD_D3: Card1.2 (CD/DAT3), U1.48 (GPIO39)
/SD_VDD: Card1.4 (VDD)
/SPI_CLK: J6.14, U1.38 (GPIO30)
/SPI_CS: J6.16, U1.37 (GPIO29)
/SPI_CS1: J6.13, U1.49 (GPIO40_ADC0)
/SPI_CS2: J6.11, U1.52 (GPIO41_ADC1)
/SPI_RX: J6.12, U1.36 (GPIO28)
/SPI_TX: J6.10, U1.39 (GPIO31)
/SWCLK: J4.1, U1.33 (SWCLK)
/SWD: J4.3, U1.34 (SWD)
/UART0_RX: J6.6, U1.78 (GPIO1)
/UART0_TX: J6.5, U1.77 (GPIO0)
/UART1_RX: J1.36 (RX), U1.28 (GPIO27)
/UART1_TX: J1.35 (TX), U1.27 (GPIO26)
/USB_D+: J1.78 (USB_DP), R7.1
/USB_D-: J1.77 (USB_DN), R8.1
/VREG_AVDD: C9.1, R3.2, U1.61 (VREG_AVDD)
/VREG_LX: L1.2, U1.63 (VREG_LX)
/WS2812_DAT: D2.2 (DOUT), J2.4
/XIN: C3.1, U1.30 (XIN), Y1.1
/XOUT: R2.1, U1.31 (XOUT)
/~A31: J1.26 (~A31), U2.5
/~INT: J1.22 (~INT), U1.21 (GPIO21)
/~IOSEL: U1.23 (GPIO23), U2.8
/~RDREQ: U1.26 (GPIO25), U2.11
/~RD: J1.25 (~RD), U2.13
/~REQ: J1.23 (~REQ), U2.12
/~RESET: J1.20 (~RESET), U1.20 (GPIO20)
/~USB_BOOT: R6.2, SW1.2
/~WAIT: J1.65 (~WAIT), U1.22 (GPIO22)
/~WR: J1.24 (~WR), U1.25 (GPIO24)
GND: C2.2, C3.2, C4.2, C6.2, C7.2, C8.2, C9.2, C10.2, C11.2, C12.2, C13.2, C14.2, C15.2, C16.2, C17.2, C18.2, C19.2, C20.2, C21.2, Card1.6 (VSS), Card1.10 (G3), Card1.11 (G4), Card1.12 (G1), Card1.13 (G2), D2.3 (VSS), J1.17 (GND), J1.39 (GND), J1.57 (GND), J1.60 (GND), J1.61 (GND), J1.66 (GND), J1.79 (GND), J2.5, J2.6, J3.1, J3.MP (MountPin), J4.2, J4.MP (MountPin), J5.1, J5.MP (MountPin), J6.3, J6.4, J6.8, R1.2, R4.2, SW1.1, U1.62 (VREG_PGND), U1.79 (GPIO2), U1.81 (GND), U2.7 (GND), U3.4 (GND), Y1.2, Y1.4
unnamed: C4.1, R2.2, Y1.3
unnamed: D1.1 (K), R1.1
unnamed: D2.1 (VDD), D3.1 (K)
unnamed: R4.1, SW2.1
unnamed: R5.2, U1.19 (GPIO19)
unnamed: R8.2, U1.66 (USB_DM)
unnamed: R7.2, U1.67 (USB_DP)
unnamed: U2.3, U2.9
unnamed: U2.6, U2.10

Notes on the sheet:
JST Debug Connector
JST QwST
Make sure R7 and R8 are close to RP2350
Flash
12MHz Crystal

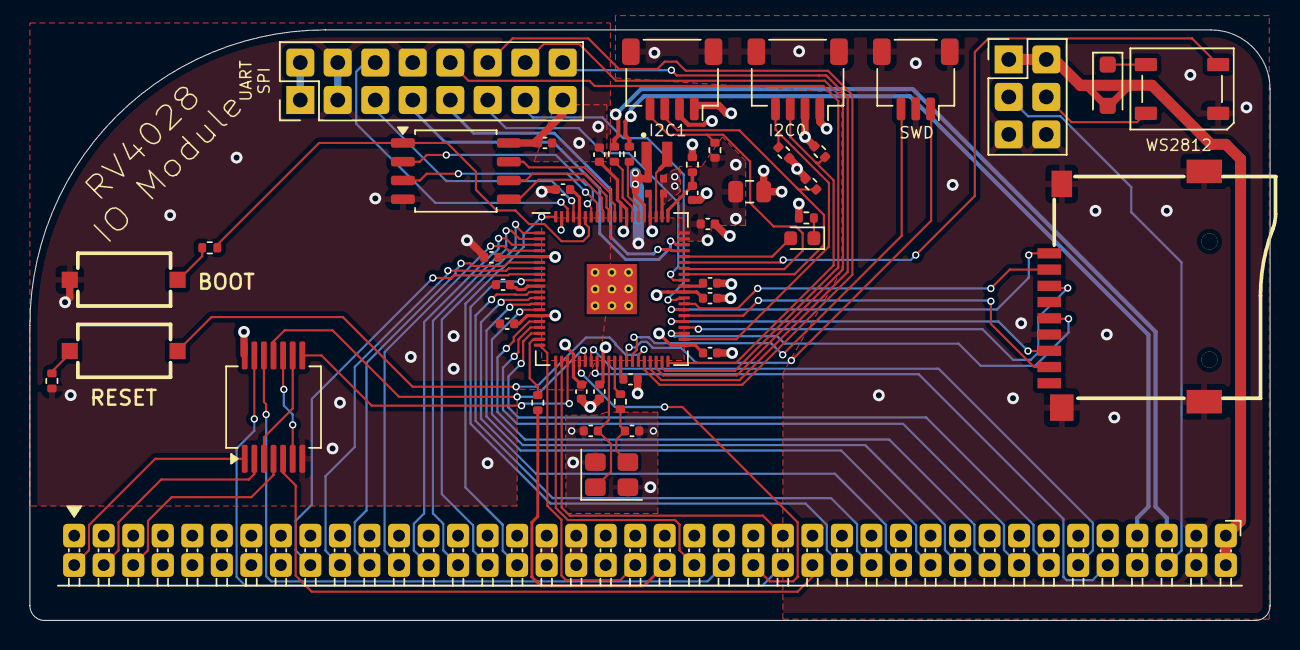
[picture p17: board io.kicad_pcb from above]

Board: 4 copper layers, 84.0 x 40.0 mm, 48 parts (0 on the bottom side), 84 nets.

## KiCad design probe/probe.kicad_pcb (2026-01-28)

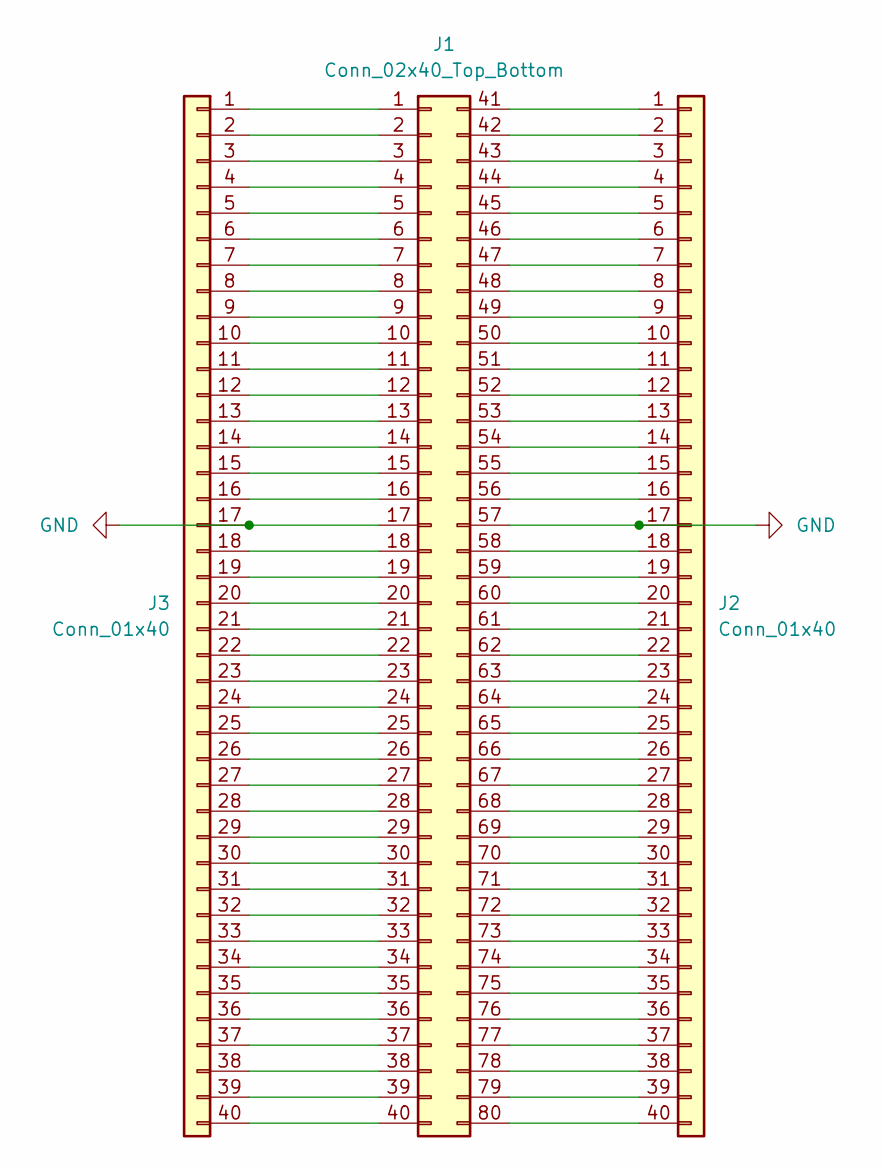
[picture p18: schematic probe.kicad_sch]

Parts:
J1: Conn_02x40_Top_Bottom; PinSocket_2x40_P2.00mm_Vertical
J2, J3: Conn_01x40; PinHeader_1x40_P2.00mm_Vertical

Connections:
GND: J1.17, J1.57, J2.17, J3.17
unnamed: J1.1, J3.1
unnamed: J1.2, J3.2
unnamed: J1.3, J3.3
unnamed: J1.4, J3.4
unnamed: J1.5, J3.5
unnamed: J1.6, J3.6
unnamed: J1.7, J3.7
unnamed: J1.8, J3.8
unnamed: J1.9, J3.9
unnamed: J1.10, J3.10
unnamed: J1.11, J3.11
unnamed: J1.12, J3.12
unnamed: J1.13, J3.13
unnamed: J1.14, J3.14
unnamed: J1.15, J3.15
unnamed: J1.16, J3.16
unnamed: J1.18, J3.18
unnamed: J1.19, J3.19
unnamed: J1.20, J3.20
unnamed: J1.21, J3.21
unnamed: J1.22, J3.22
unnamed: J1.23, J3.23
unnamed: J1.24, J3.24
unnamed: J1.25, J3.25
unnamed: J1.26, J3.26
unnamed: J1.27, J3.27
unnamed: J1.28, J3.28
unnamed: J1.29, J3.29
unnamed: J1.30, J3.30
unnamed: J1.31, J3.31
unnamed: J1.32, J3.32
unnamed: J1.33, J3.33
unnamed: J1.34, J3.34
unnamed: J1.35, J3.35
unnamed: J1.36, J3.36
unnamed: J1.37, J3.37
unnamed: J1.38, J3.38
unnamed: J1.39, J3.39
unnamed: J1.40, J3.40
unnamed: J1.41, J2.1
unnamed: J1.42, J2.2
unnamed: J1.43, J2.3
unnamed: J1.44, J2.4
unnamed: J1.45, J2.5
unnamed: J1.46, J2.6
unnamed: J1.47, J2.7
unnamed: J1.48, J2.8
unnamed: J1.49, J2.9
unnamed: J1.50, J2.10
unnamed: J1.51, J2.11
unnamed: J1.52, J2.12
unnamed: J1.53, J2.13
unnamed: J1.54, J2.14
unnamed: J1.55, J2.15
unnamed: J1.56, J2.16
unnamed: J1.58, J2.18
unnamed: J1.59, J2.19
unnamed: J1.60, J2.20
unnamed: J1.61, J2.21
unnamed: J1.62, J2.22
unnamed: J1.63, J2.23
unnamed: J1.64, J2.24
unnamed: J1.65, J2.25
unnamed: J1.66, J2.26
unnamed: J1.67, J2.27
unnamed: J1.68, J2.28
unnamed: J1.69, J2.29
unnamed: J1.70, J2.30
unnamed: J1.71, J2.31
unnamed: J1.72, J2.32
unnamed: J1.73, J2.33
unnamed: J1.74, J2.34
unnamed: J1.75, J2.35
unnamed: J1.76, J2.36
unnamed: J1.77, J2.37
unnamed: J1.78, J2.38
unnamed: J1.79, J2.39
unnamed: J1.80, J2.40

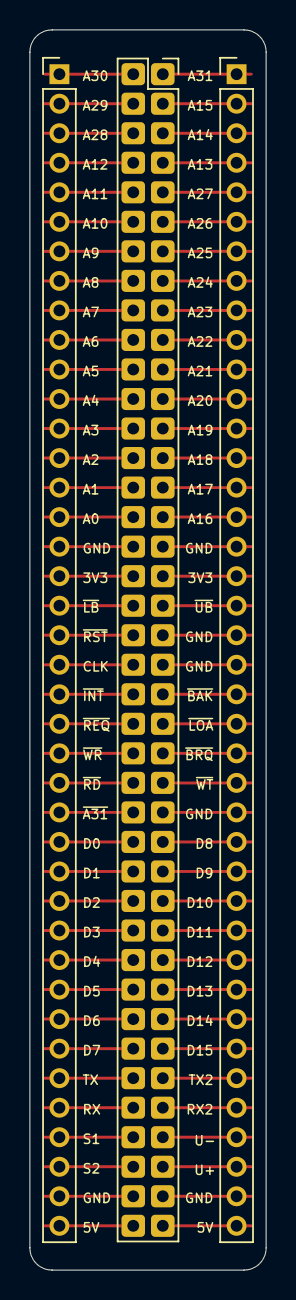
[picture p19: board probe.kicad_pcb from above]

Board: 2 copper layers, 16.0 x 84.0 mm, 3 parts (0 on the bottom side), 79 nets.

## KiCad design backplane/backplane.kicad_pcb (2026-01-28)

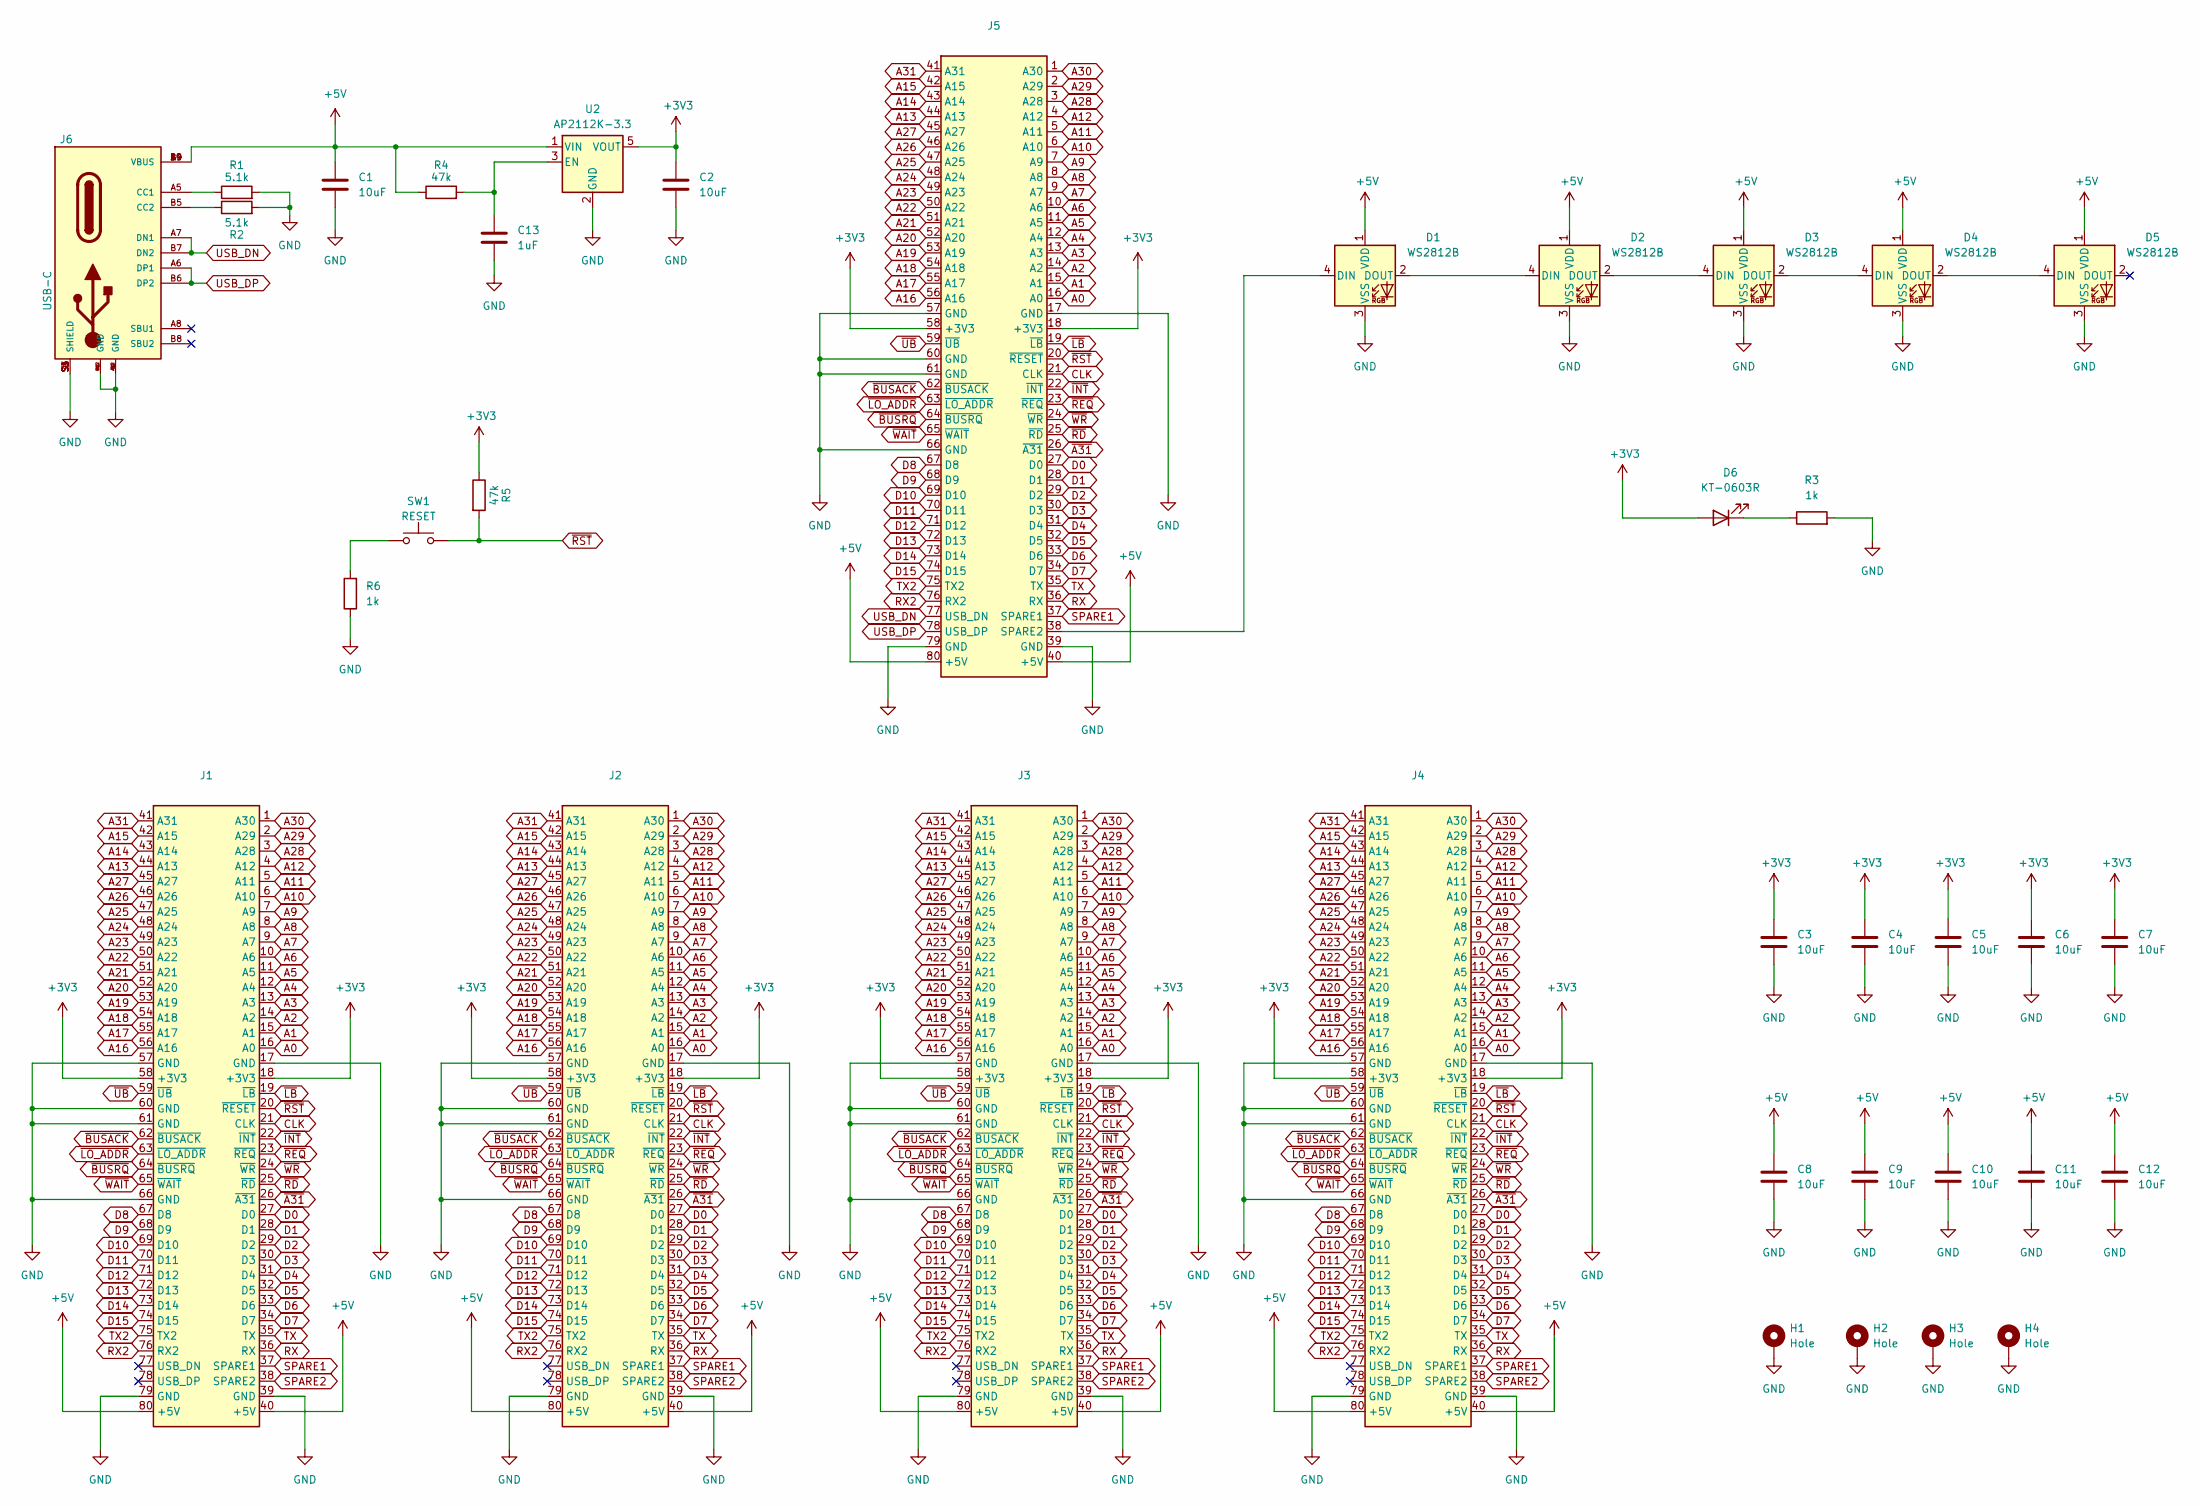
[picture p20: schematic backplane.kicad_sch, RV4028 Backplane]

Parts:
C1, C2, C3, C4, C5, C6, C7, C8, C9, C10, C11, C12: 10uF; C_0603_1608Metric
C13: 1uF; C_0402_1005Metric
D1, D2, D3, D4, D5: WS2812B; LED_WS2812B_PLCC4_5.0x5.0mm_P3.2mm; JLC C42417498
D6: KT-0603R; LED_0603_1608Metric; JLC C2286
H1, H2, H3, H4: Hole; MountingHole_2.7mm_M2.5_DIN965_Pad
J1, J2, J3, J4, J5: Backplane_Header_2mm; JLC C343635
J6: USB-C; TYPE-C-SMD_MC-107DJ; MPN USB4500-03-0-A; JLC C3039323
R1, R2: 5.1k; R_0402_1005Metric
R3, R6: 1k; R_0402_1005Metric
R4, R5: 47k; R_0402_1005Metric
SW1: RESET; SW-SMD_HX-TS-1101-C-W; JLC C36498960
U2: AP2112K-3.3; SOT-23-5; JLC C51118

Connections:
+3V3: C2.1, C3.1, C4.1, C5.1, C6.1, C7.1, D6.2 (A), J1.18 (+3V3), J1.58 (+3V3), J2.18 (+3V3), J2.58 (+3V3), J3.18 (+3V3), J3.58 (+3V3), J4.18 (+3V3), J4.58 (+3V3), J5.18 (+3V3), J5.58 (+3V3), R5.1, U2.5 (VOUT)
+5V: C1.1, C8.1, C9.1, C10.1, C11.1, C12.1, D1.1 (VDD), D2.1 (VDD), D3.1 (VDD), D4.1 (VDD), D5.1 (VDD), J1.40 (+5V), J1.80 (+5V), J2.40 (+5V), J2.80 (+5V), J3.40 (+5V), J3.80 (+5V), J4.40 (+5V), J4.80 (+5V), J5.40 (+5V), J5.80 (+5V), J6.A4 (VBUS), J6.A9 (VBUS), J6.B4 (VBUS), J6.B9 (VBUS), R4.1, U2.1 (VIN)
A0: J1.16 (A0), J2.16 (A0), J3.16 (A0), J4.16 (A0), J5.16 (A0)
A1: J1.15 (A1), J2.15 (A1), J3.15 (A1), J4.15 (A1), J5.15 (A1)
A2: J1.14 (A2), J2.14 (A2), J3.14 (A2), J4.14 (A2), J5.14 (A2)
A3: J1.13 (A3), J2.13 (A3), J3.13 (A3), J4.13 (A3), J5.13 (A3)
A4: J1.12 (A4), J2.12 (A4), J3.12 (A4), J4.12 (A4), J5.12 (A4)
A5: J1.11 (A5), J2.11 (A5), J3.11 (A5), J4.11 (A5), J5.11 (A5)
A6: J1.10 (A6), J2.10 (A6), J3.10 (A6), J4.10 (A6), J5.10 (A6)
A7: J1.9 (A7), J2.9 (A7), J3.9 (A7), J4.9 (A7), J5.9 (A7)
A8: J1.8 (A8), J2.8 (A8), J3.8 (A8), J4.8 (A8), J5.8 (A8)
A9: J1.7 (A9), J2.7 (A9), J3.7 (A9), J4.7 (A9), J5.7 (A9)
A10: J1.6 (A10), J2.6 (A10), J3.6 (A10), J4.6 (A10), J5.6 (A10)
A11: J1.5 (A11), J2.5 (A11), J3.5 (A11), J4.5 (A11), J5.5 (A11)
A12: J1.4 (A12), J2.4 (A12), J3.4 (A12), J4.4 (A12), J5.4 (A12)
A13: J1.44 (A13), J2.44 (A13), J3.44 (A13), J4.44 (A13), J5.44 (A13)
A14: J1.43 (A14), J2.43 (A14), J3.43 (A14), J4.43 (A14), J5.43 (A14)
A15: J1.42 (A15), J2.42 (A15), J3.42 (A15), J4.42 (A15), J5.42 (A15)
A16: J1.56 (A16), J2.56 (A16), J3.56 (A16), J4.56 (A16), J5.56 (A16)
A17: J1.55 (A17), J2.55 (A17), J3.55 (A17), J4.55 (A17), J5.55 (A17)
A18: J1.54 (A18), J2.54 (A18), J3.54 (A18), J4.54 (A18), J5.54 (A18)
A19: J1.53 (A19), J2.53 (A19), J3.53 (A19), J4.53 (A19), J5.53 (A19)
A20: J1.52 (A20), J2.52 (A20), J3.52 (A20), J4.52 (A20), J5.52 (A20)
A21: J1.51 (A21), J2.51 (A21), J3.51 (A21), J4.51 (A21), J5.51 (A21)
A22: J1.50 (A22), J2.50 (A22), J3.50 (A22), J4.50 (A22), J5.50 (A22)
A23: J1.49 (A23), J2.49 (A23), J3.49 (A23), J4.49 (A23), J5.49 (A23)
A24: J1.48 (A24), J2.48 (A24), J3.48 (A24), J4.48 (A24), J5.48 (A24)
A25: J1.47 (A25), J2.47 (A25), J3.47 (A25), J4.47 (A25), J5.47 (A25)
A26: J1.46 (A26), J2.46 (A26), J3.46 (A26), J4.46 (A26), J5.46 (A26)
A27: J1.45 (A27), J2.45 (A27), J3.45 (A27), J4.45 (A27), J5.45 (A27)
A28: J1.3 (A28), J2.3 (A28), J3.3 (A28), J4.3 (A28), J5.3 (A28)
A29: J1.2 (A29), J2.2 (A29), J3.2 (A29), J4.2 (A29), J5.2 (A29)
A30: J1.1 (A30), J2.1 (A30), J3.1 (A30), J4.1 (A30), J5.1 (A30)
A31: J1.41 (A31), J2.41 (A31), J3.41 (A31), J4.41 (A31), J5.41 (A31)
CLK: J1.21 (CLK), J2.21 (CLK), J3.21 (CLK), J4.21 (CLK), J5.21 (CLK)
D0: J1.27 (D0), J2.27 (D0), J3.27 (D0), J4.27 (D0), J5.27 (D0)
D1: J1.28 (D1), J2.28 (D1), J3.28 (D1), J4.28 (D1), J5.28 (D1)
D2: J1.29 (D2), J2.29 (D2), J3.29 (D2), J4.29 (D2), J5.29 (D2)
D3: J1.30 (D3), J2.30 (D3), J3.30 (D3), J4.30 (D3), J5.30 (D3)
D4: J1.31 (D4), J2.31 (D4), J3.31 (D4), J4.31 (D4), J5.31 (D4)
D5: J1.32 (D5), J2.32 (D5), J3.32 (D5), J4.32 (D5), J5.32 (D5)
D6: J1.33 (D6), J2.33 (D6), J3.33 (D6), J4.33 (D6), J5.33 (D6)
D7: J1.34 (D7), J2.34 (D7), J3.34 (D7), J4.34 (D7), J5.34 (D7)
D8: J1.67 (D8), J2.67 (D8), J3.67 (D8), J4.67 (D8), J5.67 (D8)
D9: J1.68 (D9), J2.68 (D9), J3.68 (D9), J4.68 (D9), J5.68 (D9)
D10: J1.69 (D10), J2.69 (D10), J3.69 (D10), J4.69 (D10), J5.69 (D10)
D11: J1.70 (D11), J2.70 (D11), J3.70 (D11), J4.70 (D11), J5.70 (D11)
D12: J1.71 (D12), J2.71 (D12), J3.71 (D12), J4.71 (D12), J5.71 (D12)
D13: J1.72 (D13), J2.72 (D13), J3.72 (D13), J4.72 (D13), J5.72 (D13)
D14: J1.73 (D14), J2.73 (D14), J3.73 (D14), J4.73 (D14), J5.73 (D14)
D15: J1.74 (D15), J2.74 (D15), J3.74 (D15), J4.74 (D15), J5.74 (D15)
GND: C1.2, C2.2, C3.2, C4.2, C5.2, C6.2, C7.2, C8.2, C9.2, C10.2, C11.2, C12.2, C13.2, D1.3 (VSS), D2.3 (VSS), D3.3 (VSS), D4.3 (VSS), D5.3 (VSS), H1.1, H2.1, H3.1, H4.1, J1.17 (GND), J1.39 (GND), J1.57 (GND), J1.60 (GND), J1.61 (GND), J1.66 (GND), J1.79 (GND), J2.17 (GND), J2.39 (GND), J2.57 (GND), J2.60 (GND), J2.61 (GND), J2.66 (GND), J2.79 (GND), J3.17 (GND), J3.39 (GND), J3.57 (GND), J3.60 (GND), J3.61 (GND), J3.66 (GND), J3.79 (GND), J4.17 (GND), J4.39 (GND), J4.57 (GND), J4.60 (GND), J4.61 (GND), J4.66 (GND), J4.79 (GND), J5.17 (GND), J5.39 (GND), J5.57 (GND), J5.60 (GND), J5.61 (GND), J5.66 (GND), J5.79 (GND), J6.1 (SHIELD), J6.A1 (GND), J6.A12 (GND), J6.B1 (GND), J6.B12 (GND), J6.S1 (SHIELD), J6.S3 (SHIELD), J6.S4 (SHIELD), R1.2, R2.2, R3.2, R6.1, U2.2 (GND)
unnamed: D1.4 (DIN), J5.38 (SPARE2)
unnamed: D1.2 (DOUT), D2.4 (DIN)
unnamed: D2.2 (DOUT), D3.4 (DIN)
unnamed: D3.2 (DOUT), D4.4 (DIN)
unnamed: D4.2 (DOUT), D5.4 (DIN)
unnamed: D6.1 (K), R3.1
unnamed: J6.A5 (CC1), R1.1
unnamed: J6.B5 (CC2), R2.1
unnamed: R6.2, SW1.1
unnamed: C13.1, R4.2, U2.3 (EN)
RX: J1.36 (RX), J2.36 (RX), J3.36 (RX), J4.36 (RX), J5.36 (RX)
RX2: J1.76 (RX2), J2.76 (RX2), J3.76 (RX2), J4.76 (RX2), J5.76 (RX2)
SPARE1: J1.37 (SPARE1), J2.37 (SPARE1), J3.37 (SPARE1), J4.37 (SPARE1), J5.37 (SPARE1)
SPARE2: J1.38 (SPARE2), J2.38 (SPARE2), J3.38 (SPARE2), J4.38 (SPARE2)
TX: J1.35 (TX), J2.35 (TX), J3.35 (TX), J4.35 (TX), J5.35 (TX)
TX2: J1.75 (TX2), J2.75 (TX2), J3.75 (TX2), J4.75 (TX2), J5.75 (TX2)
USB_DN: J5.77 (USB_DN), J6.A7 (DN1), J6.B7 (DN2)
USB_DP: J5.78 (USB_DP), J6.A6 (DP1), J6.B6 (DP2)
~A31: J1.26 (~A31), J2.26 (~A31), J3.26 (~A31), J4.26 (~A31), J5.26 (~A31)
~BUSACK: J1.62 (~BUSACK), J2.62 (~BUSACK), J3.62 (~BUSACK), J4.62 (~BUSACK), J5.62 (~BUSACK)
~BUSRQ: J1.64 (~BUSRQ), J2.64 (~BUSRQ), J3.64 (~BUSRQ), J4.64 (~BUSRQ), J5.64 (~BUSRQ)
~INT: J1.22 (~INT), J2.22 (~INT), J3.22 (~INT), J4.22 (~INT), J5.22 (~INT)
~LB: J1.19 (~LB), J2.19 (~LB), J3.19 (~LB), J4.19 (~LB), J5.19 (~LB)
~LO_ADDR: J1.63 (~LO_ADDR), J2.63 (~LO_ADDR), J3.63 (~LO_ADDR), J4.63 (~LO_ADDR), J5.63 (~LO_ADDR)
~RD: J1.25 (~RD), J2.25 (~RD), J3.25 (~RD), J4.25 (~RD), J5.25 (~RD)
~REQ: J1.23 (~REQ), J2.23 (~REQ), J3.23 (~REQ), J4.23 (~REQ), J5.23 (~REQ)
~RST: J1.20 (~RESET), J2.20 (~RESET), J3.20 (~RESET), J4.20 (~RESET), J5.20 (~RESET), R5.2, SW1.2
~UB: J1.59 (~UB), J2.59 (~UB), J3.59 (~UB), J4.59 (~UB), J5.59 (~UB)
~WAIT: J1.65 (~WAIT), J2.65 (~WAIT), J3.65 (~WAIT), J4.65 (~WAIT), J5.65 (~WAIT)
~WR: J1.24 (~WR), J2.24 (~WR), J3.24 (~WR), J4.24 (~WR), J5.24 (~WR)

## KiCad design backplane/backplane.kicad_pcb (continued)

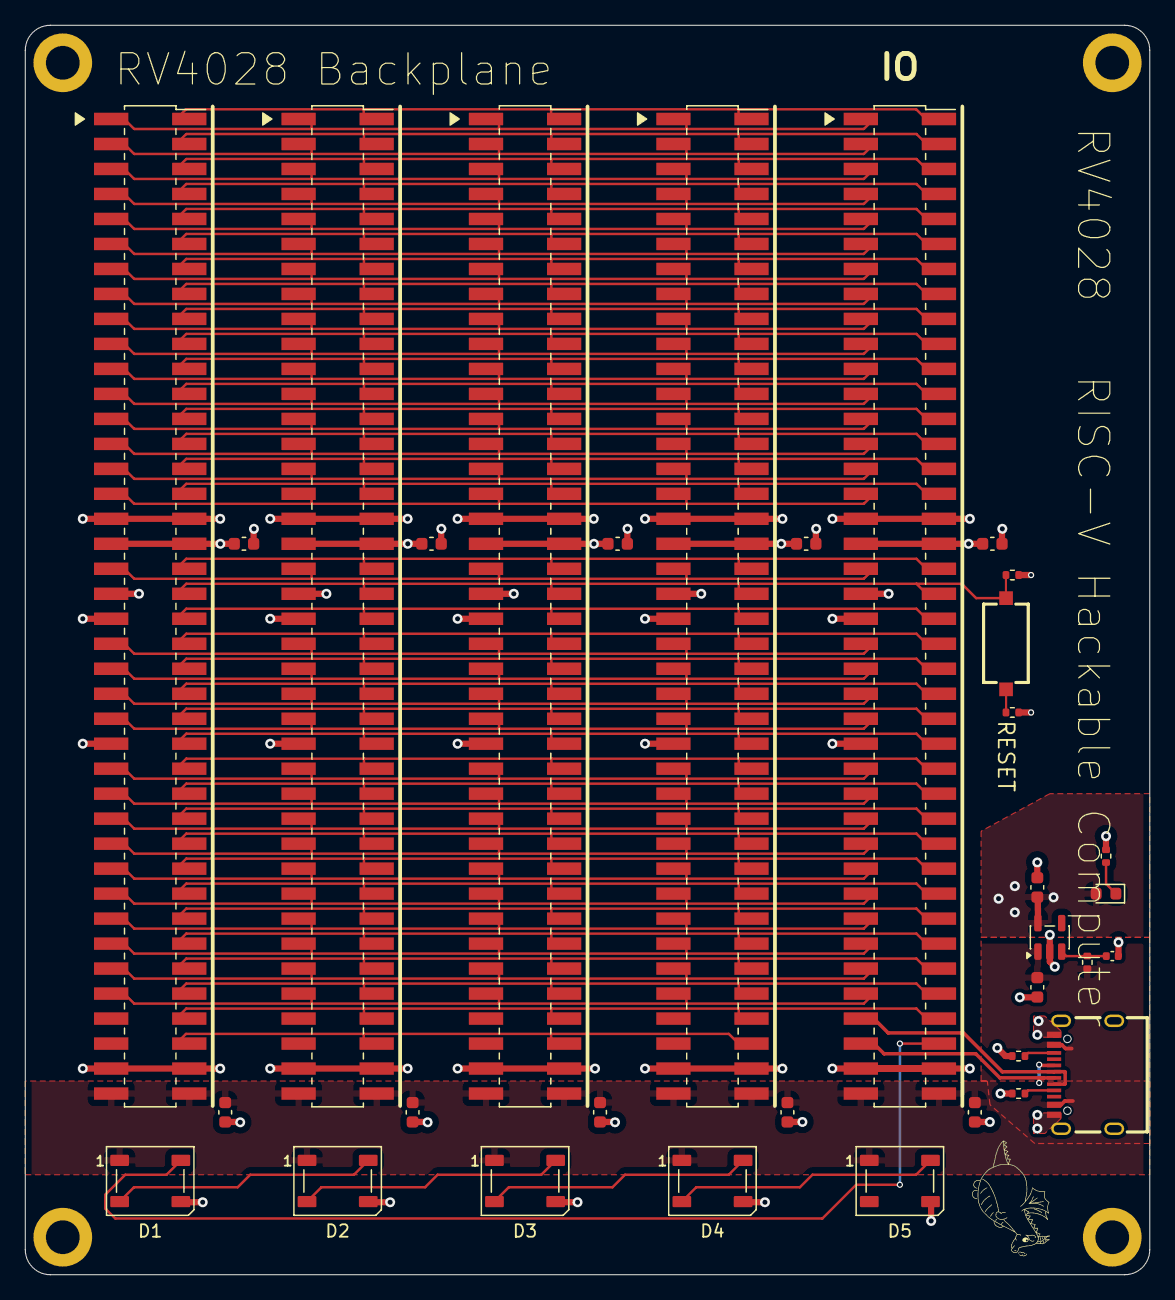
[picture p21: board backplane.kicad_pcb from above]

Board: 4 copper layers, 90.0 x 100.0 mm, 37 parts (0 on the bottom side), 82 nets.

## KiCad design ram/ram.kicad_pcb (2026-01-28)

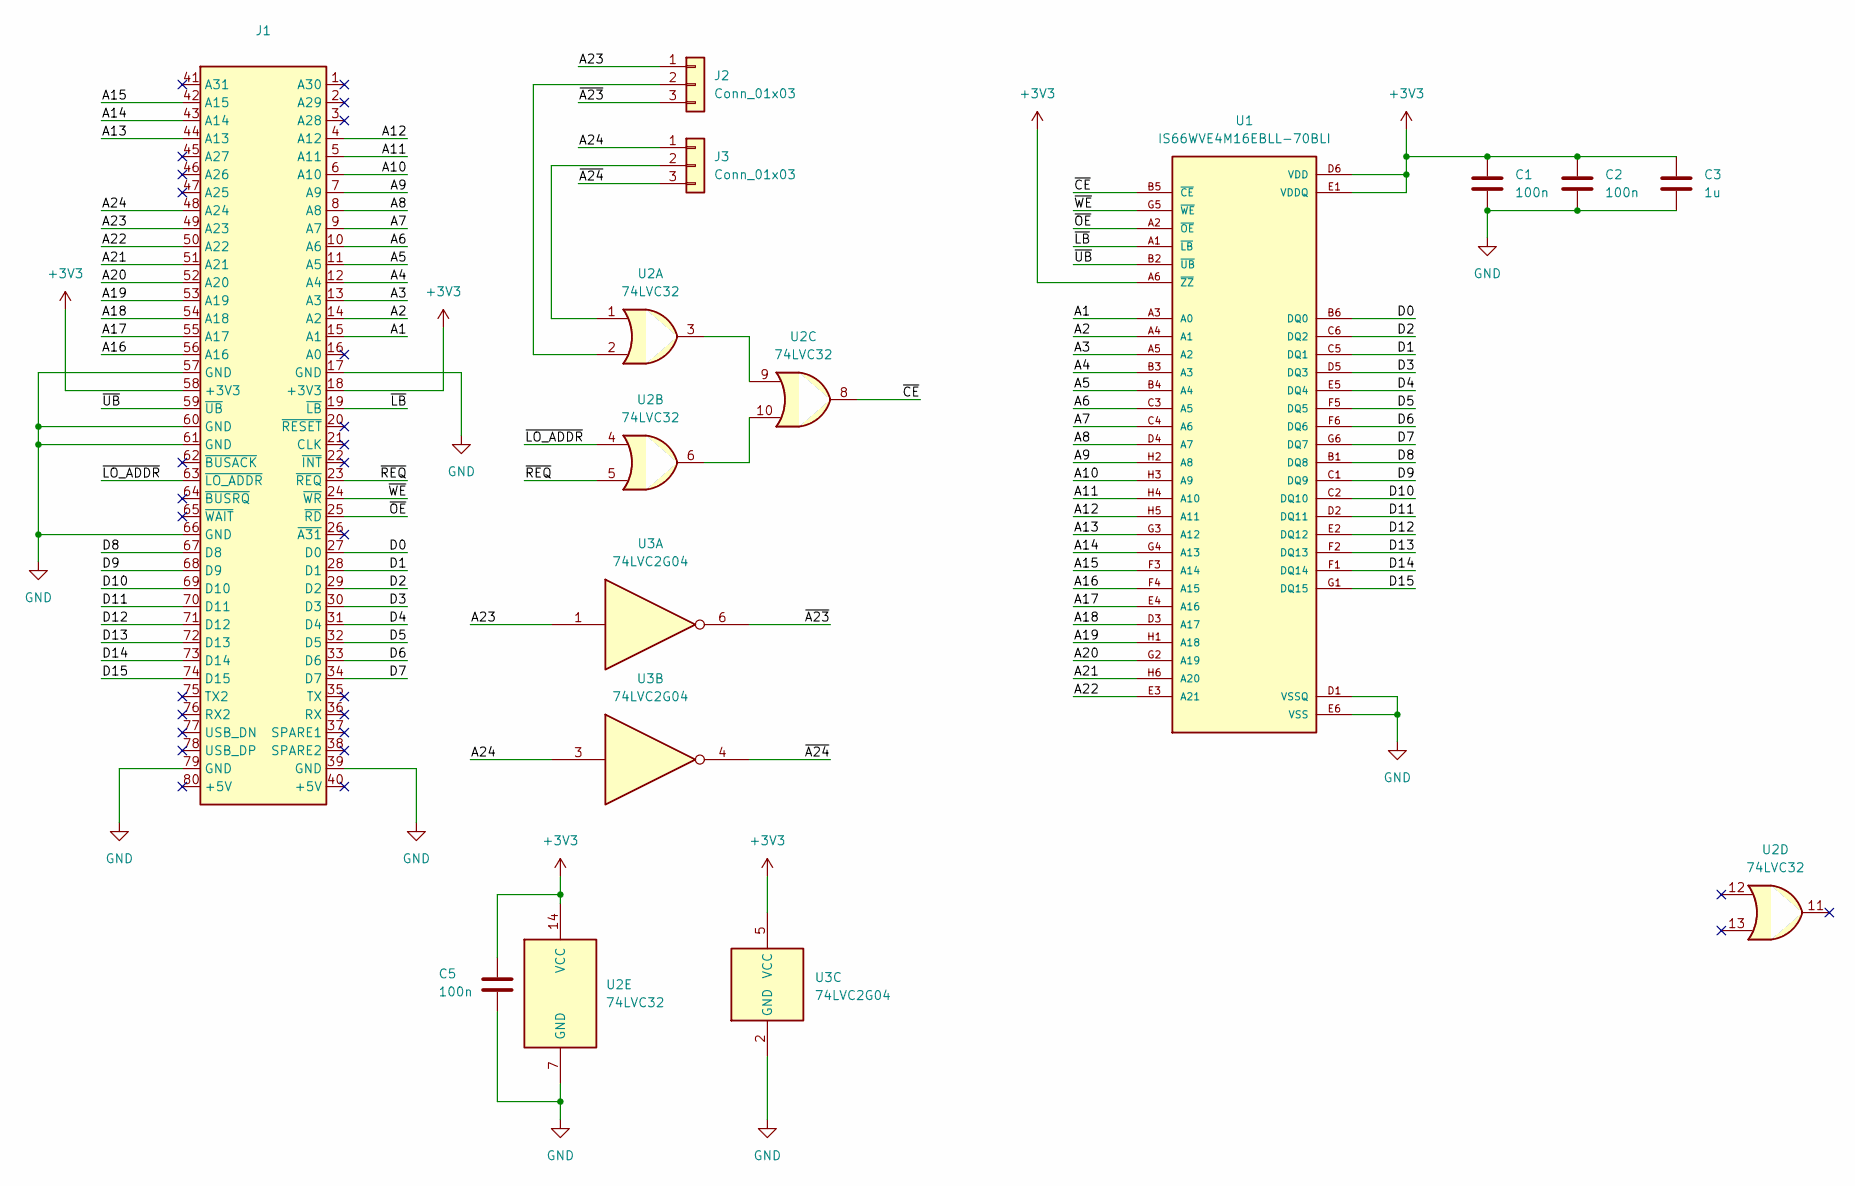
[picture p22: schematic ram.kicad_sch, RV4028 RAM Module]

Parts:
C1, C2, C5: 100n; C_0402_1005Metric
C3: 1u; C_0603_1608Metric
J1: Module_2mm; JLC C3407
J2, J3: Conn_01x03; PinHeader_1x03_P2.54mm_Vertical; JLC C49257
U1: IS66WVE4M16EBLL-70BLI; BGA48C75P8X6_800X600X120N; PARTREV D2; JLC C1350157
U2: 74LVC32; SSOP-14_5.3x6.2mm_P0.65mm; JLC C2867091
U3: 74LVC2G04; SOT-363_SC-70-6; JLC C105251

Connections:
+3V3: C1.1, C2.1, C3.1, C5.1, J1.18 (+3V3), J1.58 (+3V3), U1.A6 (~ZZ), U1.D6 (VDD), U1.E1 (VDDQ), U2.14 (VCC), U3.5 (VCC)
/A1: J1.15 (A1), U1.A3 (A0)
/A2: J1.14 (A2), U1.A4 (A1)
/A3: J1.13 (A3), U1.A5 (A2)
/A4: J1.12 (A4), U1.B3 (A3)
/A5: J1.11 (A5), U1.B4 (A4)
/A6: J1.10 (A6), U1.C3 (A5)
/A7: J1.9 (A7), U1.C4 (A6)
/A8: J1.8 (A8), U1.D4 (A7)
/A9: J1.7 (A9), U1.H2 (A8)
/A10: J1.6 (A10), U1.H3 (A9)
/A11: J1.5 (A11), U1.H4 (A10)
/A12: J1.4 (A12), U1.H5 (A11)
/A13: J1.44 (A13), U1.G3 (A12)
/A14: J1.43 (A14), U1.G4 (A13)
/A15: J1.42 (A15), U1.F3 (A14)
/A16: J1.56 (A16), U1.F4 (A15)
/A17: J1.55 (A17), U1.E4 (A16)
/A18: J1.54 (A18), U1.D3 (A17)
/A19: J1.53 (A19), U1.H1 (A18)
/A20: J1.52 (A20), U1.G2 (A19)
/A21: J1.51 (A21), U1.H6 (A20)
/A22: J1.50 (A22), U1.E3 (A21)
/A23: J1.49 (A23), J2.1, U3.1
/A24: J1.48 (A24), J3.1, U3.3
/D0: J1.27 (D0), U1.B6 (DQ0)
/D1: J1.28 (D1), U1.C5 (DQ1)
/D2: J1.29 (D2), U1.C6 (DQ2)
/D3: J1.30 (D3), U1.D5 (DQ3)
/D4: J1.31 (D4), U1.E5 (DQ4)
/D5: J1.32 (D5), U1.F5 (DQ5)
/D6: J1.33 (D6), U1.F6 (DQ6)
/D7: J1.34 (D7), U1.G6 (DQ7)
/D8: J1.67 (D8), U1.B1 (DQ8)
/D9: J1.68 (D9), U1.C1 (DQ9)
/D10: J1.69 (D10), U1.C2 (DQ10)
/D11: J1.70 (D11), U1.D2 (DQ11)
/D12: J1.71 (D12), U1.E2 (DQ12)
/D13: J1.72 (D13), U1.F2 (DQ13)
/D14: J1.73 (D14), U1.F1 (DQ14)
/D15: J1.74 (D15), U1.G1 (DQ15)
/~A23: J2.3, U3.6
/~A24: J3.3, U3.4
/~CE: U1.B5 (~CE), U2.8
/~LB: J1.19 (~LB), U1.A1 (~LB)
/~LO_ADDR: J1.63 (~LO_ADDR), U2.4
/~OE: J1.25 (~RD), U1.A2 (~OE)
/~REQ: J1.23 (~REQ), U2.5
/~UB: J1.59 (~UB), U1.B2 (~UB)
/~WE: J1.24 (~WR), U1.G5 (~WE)
GND: C1.2, C2.2, C3.2, C5.2, J1.17 (GND), J1.39 (GND), J1.57 (GND), J1.60 (GND), J1.61 (GND), J1.66 (GND), J1.79 (GND), U1.D1 (VSSQ), U1.E6 (VSS), U2.7 (GND), U3.2 (GND)
unnamed: J2.2, U2.2
unnamed: J3.2, U2.1
unnamed: U2.3, U2.9
unnamed: U2.6, U2.10

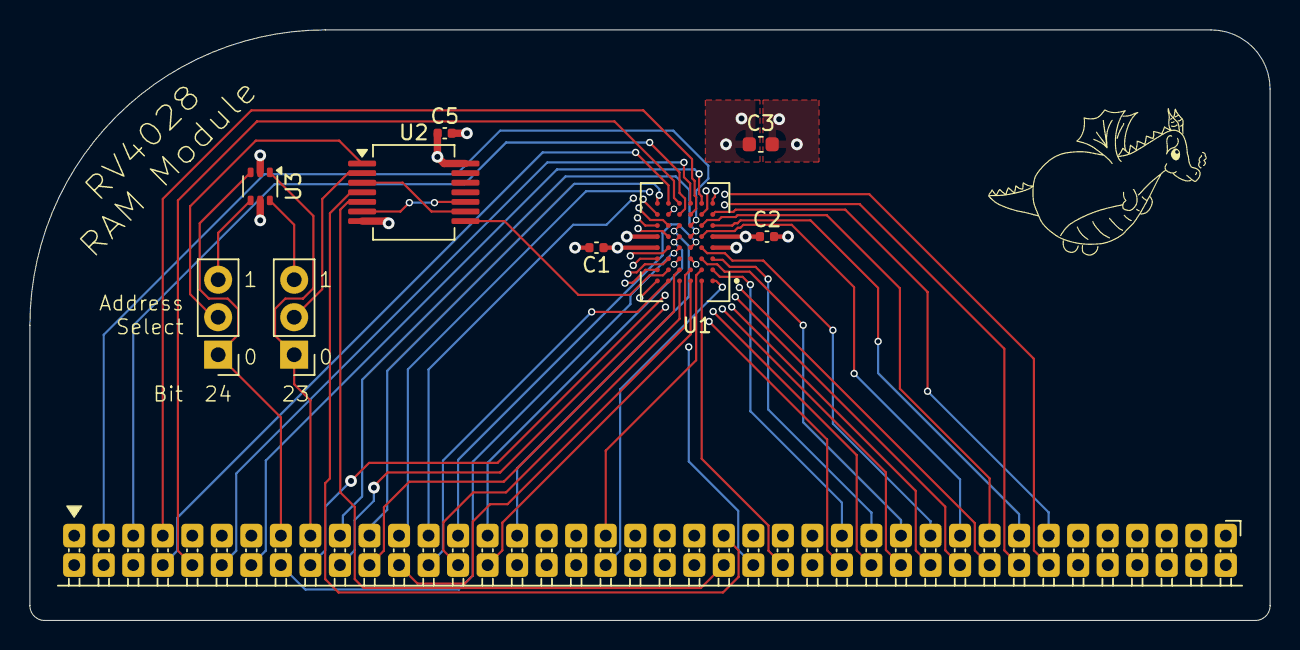
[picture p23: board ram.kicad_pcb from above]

Board: 4 copper layers, 84.0 x 40.0 mm, 10 parts (0 on the bottom side), 55 nets.

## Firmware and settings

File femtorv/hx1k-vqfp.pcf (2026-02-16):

# PCF for possible HX1k VQFP for RV4028 (Risc-V RC2014-alike)

set_io clk 62
set_io rst_n 63

set_io addr[31] 1
set_io addr[30] 2
set_io addr[29] 4
set_io addr[28] 8
set_io addr[27] 12
set_io addr[26] 15
set_io addr[25] 18
set_io addr[24] 20
set_io addr[23] 24
set_io addr[22] 26
set_io addr[21] 28
set_io addr[20] 30
set_io addr[19] 37
set_io addr[18] 51
set_io addr[17] 53
set_io addr[16] 56
set_io addr[15] 3
set_io addr[14] 7
set_io addr[13] 9
set_io addr[12] 10
set_io addr[11] 13
set_io addr[10] 16
set_io addr[9] 19
set_io addr[8] 21
set_io addr[7] 25
set_io addr[6] 27
set_io addr[5] 29
set_io addr[4] 36
set_io addr[3] 40
set_io addr[2] 52
set_io addr[1] 54
set_io addr[0] 57

set_io wr_n 68
set_io rd_n 71
set_io msk_n[0] 60
set_io msk_n[1] 59
set_io iorq_n 73
set_io req_n 66
set_io wait_n 69
set_io lo_addr_n 65
set_io busrq_n 41
set_io busack_n 42

set_io int_n  64

set_io data[0] 78
set_io data[1] 80
set_io data[2] 82
set_io data[3] 85
set_io data[4] 87
set_io data[5] 93
set_io data[6] 95
set_io data[7] 97
set_io data[8] 74
set_io data[9] 79
set_io data[10] 81
set_io data[11] 83
set_io data[12] 86
set_io data[13] 91
set_io data[14] 94
set_io data[15] 96

set_io spare[1] 89
set_io spare[2] 90

set_io led 100
set_io spare[0] 99

set_frequency clk 20

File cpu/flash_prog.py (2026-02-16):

import time
import machine
from machine import SPI, Pin

def release_pins():
    for i in range(30):
        Pin(i, Pin.IN, pull=None)
    

def program(filename):
    release_pins()

    flash_sel = Pin(5, Pin.IN, Pin.PULL_UP)
    ice_creset_b = machine.Pin(6, machine.Pin.OUT)
    ice_creset_b.value(0)

    spi = SPI(0, 10_000_000, sck=Pin(2), mosi=Pin(3), miso=Pin(4))

    flash_sel = Pin(5, Pin.OUT)
    flash_sel.on()

    def flash_cmd(data, dummy_len=0, read_len=0):
        dummy_buf = bytearray(dummy_len)
        read_buf = bytearray(read_len)
        
        flash_sel.off()
        spi.write(bytearray(data))
        if dummy_len > 0:
            spi.readinto(dummy_buf)
        if read_len > 0:
            spi.readinto(read_buf)
        flash_sel.on()
        
        return read_buf

    def flash_cmd2(data, data2):
        flash_sel.off()
        spi.write(bytearray(data))
        spi.write(data2)
        flash_sel.on()

    def print_bytes(data):
        for b in data: print("%02x " % (b,), end="")
        print()

    CMD_WRITE = 0x02
    CMD_READ = 0x03
    CMD_READ_SR1 = 0x05
    CMD_WEN = 0x06
    CMD_SECTOR_ERASE = 0x20
    CMD_ID  = 0x90
    CMD_REL_PD  = 0xAB
    CMD_LEAVE_CM = 0xFF

    flash_cmd([CMD_REL_PD])
    time.sleep_us(3)
    flash_cmd([CMD_LEAVE_CM])
    id = flash_cmd([CMD_ID], 2, 3)
    print_bytes(id)
    
    with open(filename, "rb") as f:
    #if False:
        buf = bytearray(4096)
        sector = 0
        while True:
            num_bytes = f.readinto(buf)
            #print_bytes(buf[:512])
            if num_bytes == 0:
                break
            
            flash_cmd([CMD_WEN])
            flash_cmd([CMD_SECTOR_ERASE, sector >> 4, (sector & 0xF) << 4, 0])

            while flash_cmd([CMD_READ_SR1], 0, 1)[0] & 1:
                print("*", end="")
                time.sleep(0.01)
            print(".", end="")

            for i in range(0, num_bytes, 256):
                flash_cmd([CMD_WEN])
                flash_cmd2([CMD_WRITE, sector >> 4, ((sector & 0xF) << 4) + (i >> 8), 0], buf[i:min(i+256, num_bytes)])

                while flash_cmd([CMD_READ_SR1], 0, 1)[0] & 1:
                    print("-", end="")
                    time.sleep(0.01)
            print(".")
            sector += 1
            
        print("Program done")

    with open(filename, "rb") as f:
        data = bytearray(256)
        i = 0
        while True:
            num_bytes = f.readinto(data)
            if num_bytes == 0:
                break
            
            data_from_flash = flash_cmd([CMD_READ, i >> 8, i & 0xFF, 0], 0, num_bytes)
            for j in range(num_bytes):
                if data[j] != data_from_flash[j]:
                    raise Exception(f"Error at {i:02x}:{j:02x}: {data[j]} != {data_from_flash[j]}")
            i += 1

    print("Verify done")
    data_from_flash = flash_cmd([CMD_READ, 0, 0, 0], 0, 16)
    print_bytes(data_from_flash)

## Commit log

2025-10-25 Update pin names
2025-10-27 CPU module
    [cpu.kicad_pcb, cpu.kicad_sch]
2025-10-31 Improve power. Start work on IO module
    [cpu.kicad_pcb, cpu.kicad_sch, io.kicad_pcb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]
2025-12-25 Updates to io board
    [io.kicad_pcb, io.kicad_sch]
2025-12-26 Fix module pin labels
    [cpu.kicad_pcb]
2026-01-02 IO module routed
    [io.kicad_pcb, io.kicad_sch]
2026-01-12 RAM module, many tweaks
    [IS66WVE4M16EBLL-70BLI.step, cpu.kicad_pcb, cpu.kicad_sch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]
2026-01-13 BGA layout is a pain
    [ram.kicad_pcb]
2026-01-13 Revised module header
    [cpu.kicad_sch, io.kicad_sch, ram.kicad_sch]
2026-01-14 Relayout CPU
    [cpu.kicad_pcb]
2026-01-19 IO module 2mm headers
    [cpu.kicad_pcb, cpu.kicad_sch, io.kicad_pcb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]
2026-01-19 CPU and IO production fixes
    [cpu.kicad_pcb, cpu.kicad_sch, io.kicad_pcb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]
2026-01-21 Add backplane
    [backplane.kicad_pcb, backplane.kicad_sch, cpu.kicad_pcb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]
2026-01-22 RAM board attempt 2
    [backplane.kicad_pcb, cpu.kicad_pcb, io.kicad_pcb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]
2026-01-22 PDFs of schematics, readme updates
    [backplane.kicad_sch, cpu.kicad_sch, io.kicad_sch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]
2026-01-22 Backplane reset and fixes
    [backplane.kicad_pcb, backplane.kicad_sch, io.kicad_pcb]
2026-01-22 Finish RAM module routing
    [cpu.kicad_pcb, io.kicad_pcb, ram.kicad_pcb]
2026-01-23 Pull up on REQ
    [cpu.kicad_pcb, cpu.kicad_sch, ram.kicad_pcb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]
2026-01-25 Mounting holes
    [backplane.kicad_pcb, backplane.kicad_sch]
2026-01-28 Review before first PCB order
    [backplane.kicad_pcb, cpu.kicad_pcb, cpu.kicad_sch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]
2026-01-29 Implement interrupts
2026-01-29 Interrupts work, but too big
2026-01-31 Updates from ICE40 checklist
    [cpu.kicad_pcb, cpu.kicad_sch]
2026-02-22 Bootloader clears LEDs

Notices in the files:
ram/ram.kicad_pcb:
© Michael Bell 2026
